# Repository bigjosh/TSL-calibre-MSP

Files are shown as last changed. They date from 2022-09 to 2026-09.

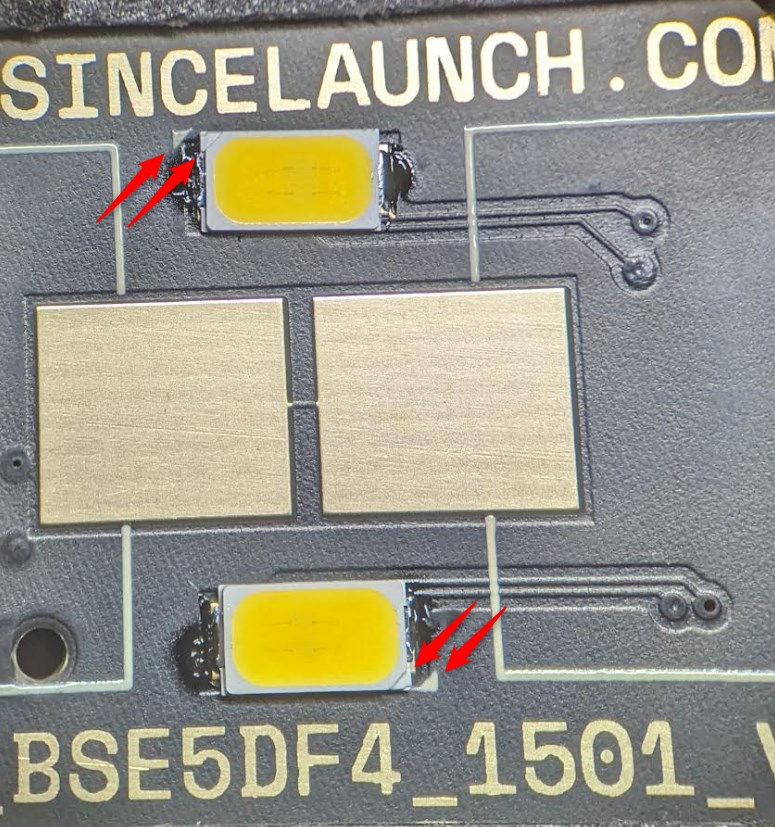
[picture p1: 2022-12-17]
hardware/assembly-package/orientaion-L1-L2.jpg

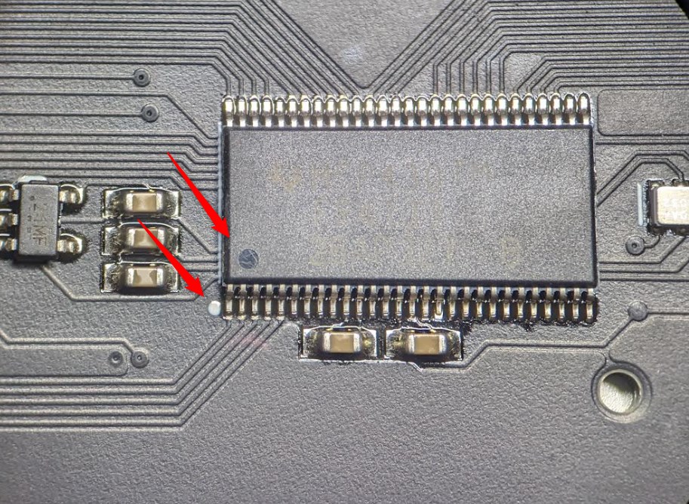
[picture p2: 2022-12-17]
hardware/assembly-package/orientaion-U1.jpg

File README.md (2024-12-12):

# TSL

PCB and firmware for the CW&T Time Since Launch project.



Buy it here...
https://cwandt.com/products/time-since-launch?variant=19682206089275

## Design goals:

* Run for decades on 2xAA batteries.
* Stay accurate to to within ±2ppm over the lifetime.  
* Replaceable batteries, with continued timekeeping during a reasonable battery swap time period.  

## Critical parts:

* MSP430FR4133 processor for LCD driving and supervision
* RV3032-C7 RTC for precision timekeeping
* Custom 12-digit, dynamic LCD glass 
* 2x Energizer Ultimate Lithium AA batteries
* Optional TPS7A0230 3V regulator for generating LCD bias voltage

## Method of Operation

### Ready To Launch mode 

Shows a mesmerizing winding pattern with 1Hz update rate. 

The purpose of this pattern is to show the user that we are ready and willing, and also make apparent any bad LCD segments stuck either on or off. 

We enter this mode on power up if the trigger pin has never been pulled before, and we exit it when the pin is pulled. 

### Time Since Launch Mode

Here we count up the days, hours, minutes, and seconds since the trigger was pulled. 

When we reach 1,000,000 days we switch to Long Now mode. 

### Long Now mode

Shows `999999 999999` blinking forevermore. 

Indicates that the trigger pull was more than 1 million days (~2740 years) ago so we can not display it accurately. 

The idea here is to avoid problems of people trying to ebay old TSL units that have rolled over by misrepresenting their true milage.

#### Errors

##### Error messages 

###### `Pin is in`
ON the first power up after programming, we check to make sure that the switch is closed which indicates that the trigger pin is out.   

##### Error Codes 

Descibed here...
[CCS%20Project/error_codes.h](CCS%20Project/error_codes.h)

### Commisioning

To commisison a new unit, we go though these steps...

1. Firmware is programmed and the display shows `FIRST START` message.
2. Power is removed from the unit.
3. When the unit sees voltage is dropping, it starts counting how many 1/64ths of a second it can keep running before it shuts down. It displays all 8's on the LCD durring this time to check for shorts on the LCD lines.
4. Batteries are insterted and the unit powers up.
5. Firmware checks to see how many 1/64ths of a second it survived during the previous power down. If this value is out of bounds (power level too low or too high) then it shows an `AMPS LO` or `AMPS HI` error.
6. The pin is inserted, depressing the trigger lever. This tests that the pin can cycle though both states.
7. Unit is ready to launch! I displays a segment pattern on the LCD that shoud update at 2Hz. This tests both that the RTC is generating interrupts correectly and also that all LCD are good. 

## Interesting twists

We are using the MSP430's Very Low Power Oscilator (VLO) to drive the LCD since it is actually lower power than the 32Khz XTAL. It is also slower, so more power savings. 

We do NOT use the MSP430's "LPMx.5" extra low power modes since they end up using more power than the "LPM4" mode that we are using. This is becuase it takes 250us to wake from the "x.5" modes and durring this time, the MCU pulls about 200uA. Since we wake 2 times per second, this is just not worth it. If we only woke every, say, 15 seconds then we could likely save ~0.3uA by using the "x.5" modes. 

To make LCD updates as power efficient as possible, we precomute the LCDMEM values for every second and minute update and store them in tables. Because we were careful to put all the segments making up both seconds digits into a single word of memory (minutes also), we can do a full update with a single 16 bit write. We further optimize but keeping the pointer to the next table lookup in a register and using the MSP430's post-decrement addressing mode to also increment the pointer for free (zero cycles). This lets us execute a full update on non-rollover seconds in only 4 instructions (not counting ISR overhead). This code is here...
[CCS%20Project/tsl_asm.asm#L91](CCS%20Project/tsl_asm.asm#L91)

## Battery changes

Based on power projections, we do not expect to need a battery change for at least 100 years. When the batteries get near thier end of life, the LCD will start to get dim. At this point, as long as the unit has been triggered, it will simply stop counting durring the time it takes to change the batteries, and will start counting again
from where it left off once the new batteries are installed. To make this possible, we keep counters of both days and minutes elapsed since trigger in FRAM. These counters are updated each minute and day respectively. Do note that this means that every time you remove the batteries, the time since launch will round down to the most recent minute. Also note that it is _possible_ to lose power exactly at the momentthat happens once per day when both the minute and day counters are updates, so there is lock code to make sure this pair of updates is atomic. 

Note that if the batteries are pulled before the unit is triggered then it will go into `BATT_ERROR_PRELAUNCH` mode ("ERROR 1"), so do not wait *too* long before triggering your TSL. :)

## Hardware revisions

The 2nd hardware revision was produced mid-2024 and removes the backup capacitors connected to the RTC and adds a new 10K OHM resistor on one of the pads that these capcitors used. Previously, these capacitors would keep the RTC continuously operating durring batter changes, but there some defects on those capacitors and we decided it would be easier to just have the count pause durring battery changes. To support this change, there is a change to the firmware that is not compatible with the old versions of the hardware. This change disables the "backup power" option on the RTC. To compile the firmware to work with this new version of the hardware, you must include `#define C2_IS_10K` in the top of `tsl-calibre-msp.cpp`. 

## Current Usage

| Mode | Vcc=3.55V| Vcc=2.6V |
| - | -: | -: |
| Ready to Launch Running | 1.3uA | 1.2uA | 
| Ready to Launch Static | 1.1uA | 1.0uA | 
| Time Since Launch | 1.8uA | 1.7uA |

3.55V is approximately the voltage of a pair of fresh Energizer Ultra batteries.
2.6V is approximately the voltage when the screen starts to become hard to read. 

Note that voltage drop over time is not expected to be linear with Energizer Ultra cells. These batteries are predicted to spend most of their lives towards the higher end of the voltage range and only start dropping when they get near to their end of life.  

There are gains possible from having fewer LCD segments lit. Not sure how actionable this is. We could, say, save 0.5uA by blinking the Time Since Launch mode screen off every other second. It is likely that Ready To Launch mode's low power relative to Time Since Launch mode is due to the fact that it has only 1 segment lit per digit. 

### Measurement conditions

Production board from initial batch. Bare PCB on my desk (not in tube).  
68F
80%RH

(Higher humidity and temperature tends to increase current consumption. Need some different weather conditions to quantify this!)

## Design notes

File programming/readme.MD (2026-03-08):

# PROGRAMMING

## One-time Set up

### Software
 1. Download `program.py`, 'addrow.py', `getch.py`, and `tsl-calibre-msp.txt` from a release in this repo.
 2. Install Python. (The TSL programming script is in Python)
 connections. 
 4. Install [MSPFlasher](https://www.ti.com/tool/MSP430-FLASHER). (This actually talks to the EZ-FET programming hardware)
 5. Make sure that the MSPFlasher executable is in the search path.

### Hardware

You will need a TI board with an EZFet programmer on it. There are lots and any will do. I used the MSP-EXP430FR4133.

2. Remove all of the jumpers on the programmer board and connect it to the computer via USB.
3. Connect the pins from the EZFet side of the programmer (the side closer to the USB) to the programming connector like this...
    | Programmer pin | TSL pin |
    | - | - | 
    | G | G |
    | 3V3 | V |
    | SBWTDIO | R | 
    | SBWTICK | T |
 
#### Config

If you are not going to use the optional logging spreadsheet, you can leave the `tsl_logscript` environment variable unset or set it to `none`.

If you are going to use logging, see the section below.

## Commissioning Procedure
1. Run the `program.py` program.
1. Connect a new TSL board without batteries to the programming connector.
2. Enter the unit's serial number. 
2. _Confirm_ that the firmware download completes without error.
3. _Confirm_ that the TSL starts, the two LEDs flash, the display shows the 'First Start' message.
4. Disconnect the programming connector. The display should show all 8's and fade out while the unit tests its power consumption. Be sure to hold the board by the edges - just touching the LCD pins can increase the power usage enough to cause the power test to fail. 
5. Within 1 minute, install the batteries into the TSL.
6. _Confirm_ that the display shows the 'Load Pin' message.
7. Assemble the TSL into the tube.
8. Insert the pull pin.
9. The display should show 'Arming' followed by the `Ready To Launch Mode` dancing dashes animation.
9. _Confirm_ that the dancing dashes display lights all the LCD segments and that it updates steadily once per second. 
10. Pack it up and ship it out!

Reject the unit if it fails any of the _confirm_ steps above.

## Optional features

### Logging spreadsheet

We optionally keep a record of every TSL programming event in a google sheet using a google app script. 

If you do not want to use this feature, leave `tsl_logscript` unset or set it to `none`.

If you do want to use logging...

6. Create a google spreadhseet with 5 columns and give them names like "Timestamp",	"Device Serial Number",	"Device UUID",	"Firmware Hash", "Programmer Mac Address" and freeze the top row.
 7. Add a webapp to the sheet with "Extentions->Appscript" and paste the code from `addrow-appscript.gs` (in this folder) into the code editor.
 8. Click "Deploy->New Deploy" and select "Run as" you and "Allow anyone".
 9. Click "Deploy" and copy the URL it gives you. 
 9. Set the envrironment variable `tsl_logscript` to this URL.

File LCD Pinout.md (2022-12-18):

## Software considerations

We want to make make sure that all segments for a given digit are accessible with a single write so that we can quickly update that digit and also not mess up any other digits. This is especially true for the most frequently updated digits like the seconds but not as important as, say, day digits since these are updated so infrequently. 

Each digit has 7 segments, and on the LCD they are arranged so that those segments are addressed via 2 segment pins * 4 common pins. 

We are using a 4-mux LCD and in this mode the MSP430 puts 2 physical pins in each writeable LCD memory register. In each MSP430 LCD memory byte, the lower 4 bits are the the 4 common pins for one segment pin and the upper 4 bit are the 4 common pins on the next segment pin. Each segment pin has a logical name starting with "L0" and counting up to "L37".

Importantly note that the pairs are always an even then odd pin number since they start at `L0/L1`. So `L22` and `L23` can be connected to the same digit on the LCD since we can update both with a single write to `LCDM11`, but if we connected LCD digit #1 to MSP pins `L21` and `L22` then we would need to write to both `LCDM11` and `LCDM10` to update the digit on the LCD display (and mess up whatever was on `L23` and `L20`).

Note that the MSP430 is a 16 bit processor, so it is also possible to update two digits with a single word write if the registers connected to them are next to each other in memory and do not cross a word boundary. This is probably only worth the additional effort to save a single cycle in the seconds digits. 

## PCB Layout considerations

Additionally we want to be able to optimize the layout of the traces to keep them short and non-overlapping. Luckily the MSP-430FR411 gives us flexibility to map the LCD common pins to any of the `L` pins on the MSP, so we can map them to `L08`-`L11` which are in the upper left corner of the MSP430, physically corresponding to the location of the common pins on the LCD.

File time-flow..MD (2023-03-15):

### Time Flow in the TSL

Naively, we should just be able to program the RTC to give us one tick per second and then just count those seconds and be done. Unfortunately, we need to be able to change the batteries, and while the batteries are out the MPU is not running so it misses counts. This leads to much complication. Here is how we solve it.

## Pre-launch

We want to be able to tell when a unit launched so we can restart it just in case there is some failure.

To do this, when we commission the TSL in the factory, we write a block to FRAM with the timedate that the RTC was first powered up. Now by adding the accumulated time to the stored time, can can determine the real world timedate. Note that we also store this commission timedate in a database , so the one in FRAM is just a backup in case that database is lost over the eons. Also note that this recorded commissioning time is never used in the operation of the unit - it is only there for forensic inspection in the case of a failure.  

There is a complication- the RTC does not store centuries so if a user waits 101 years before pulling the trigger then we can not tell if this was 1 year or 101 years by looking only at the data. We resolve this for TSLs that have had the triggered pulled (the only case where this matters) by looking to the time since launch to disambiguate how many centuries have past since manufacturing and then allocate them between pre- and post- launch periods. 

# Ready to Launch mode

When the trigger is pulled, we read the current timedate from the RTC (which represents the time since commissioning modulo 100 years) and write it to an FRAM block as the "launch" time. Note that this is only here for forensic purposes and is never used by the unit. We then reset the RTC to 1/1/00 00:00:00 and let it start counting. This way the time in the RTC represents the amount of time since launch. After that, the unit starts counting the ticks and updating the display. Note that we do not ever use the timeday being maintained inside the RTC during operation - the MCU keeps its own timedate based on counting ticks.

The MCU keeps the seconds, minutes, and hours in registers for efficiency. It keeps the day count as an unsigned long in FRAM.  

# Battery change event

During a battery change, the MCU is powered down but the RTC continues timekeeping using a backup capacitor that can keep it running for at least a minute.

So when we power back up again after a battery change, the seconds, minutes, and hours registers are lost - but we can read these from the RTC. 

We do still know the day count because that was stored in FRAM, but there is a complication. What if the battery is pulled at 23:59:59 and then reinserted at 00:00:30? Now we will have the correct seconds, minutes, and hours but will will have missed a day. 

To resolve this, we keep an extra flag in FRAM called `bottom_of_day_flag`. We set this flag when hours goes from 11 to 12 and clear it when we count a new day (hours goes from 23 to 0).

In Ready To Launch mode

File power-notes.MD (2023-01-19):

# Power Notes

All measurements taken with display initialized to "bA9876543210".

Vcc= 3.51V.

2.12uA Count switching between 00 and 01 at 2hz. 
2.00uA with ~INT unplugged so no interrupts or display updates, display at 01.

0.39uA just RTC with 2.hz ~INT and direct switching mode.

2.05uA with RTC connected
1.67uA without RTC connected

### RTC Backup Modes Power Usage
1.23uA RTC at default power up with clkout 32768
0.17uA RTC with clkout disabled, backup disabled
0.18uA RTC with direct switchover mode enabled

-- So direct switchover mode is very power cheap, so probably not worth adding a diode to save 0.01uA.

#### RTC Periodic Timer Power Usage

0.40uA RTC with 2Hz periodic timer off the 4096Hz base
0.34uA RTC with 1/64Hz periodic timer off the 64Hz base.
0.34uA RTC with 1/4096Hz periodic time off the 1Hz base.

--So the periodic timer uses ~0.16uA even on low base frequencies. Wish I had know that before!

0.18uA RTC with 1Hz square wave on clkout

--So clkout is the efficient way to go. :/

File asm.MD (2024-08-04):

# Why Assembly?

We use pure assembly in the `tsl_asm.asm` file for running in Time-Since-Launch mode because it saves power.

The fastest I could do using pure C was to use a RAM table of words that gets written to the LCD memory on each tick. The code looks like this...

```
__interrupt void rtc_isr(void) {
	if (mode=TSL_MODE) {
		*secs_lcdmem_word = secs_lcd_words[  secs ];
		secs+;
		if (secs==60) {
			/* Handle next minute */
		}
	}
 	CBI( RV3032_CLKOUT_PIFG , RV3032_CLKOUT_B );      // Clear the pending RV3032 INT interrupt flag that got us into this ISR.
}
```

The compiler didn't handle the memory to memory assignment so Well, so I optimized it to...

```
__interrupt void rtc_isr(void) {
	if (mode=TSL_MODE) {
        asm("        MOV.B     &secs+0,r15           ; [] |../tsl-calibre-msp.cpp:1390| ");
        asm("        RLAM.W    #1,r15                ; [] |../tsl-calibre-msp.cpp:1390| ");
        asm("        MOV.W     secs_lcd_words+0(r15),(LCDM0W_L+16) ; [] |../tsl-calibre-msp.cpp:1390|");
		secs+;
		if (secs==60) {
			/* Handle next minute */
		}
	}
 	CBI( RV3032_CLKOUT_PIFG , RV3032_CLKOUT_B );      // Clear the pending RV3032 INT interrupt flag that got us into this ISR.
}
```

....which executes in 43.6us per tick. 

This is very inefficient because the compiler generated ISR saves and reloads the registers on each call, even though *we* know that nothing else can run since the CPU is sleeping between ticks. 

So it seems the only solution is to write directly in asm where we can load the registers up once on starting the mode and then even load them again. 

Here is the oltimate ASM code to update the seconds digit on each tick...

```
TSL_MODE_ISR

 	  		;OR.B      	#128,&PAOUT_L+0  			; Set DEBUGA for profiling purposes.

 	  		; These next 3 lines are where this product spends the *VAST* majority of its life, so we hyper-optimize.

 	  		MOV.W		@R6+,&(LCDM0W_L+16)			; Read word value from table, increment the pointer, then write the word to the LCDMEM for the Seconds digits

			CMP.W		R6,R5						; Check if we have reached the end of the seconds table (seconds incremented to 60)
			JNE			TSL_DONE					; This takes 2 cycles, branch taken or not

			; Next minute
```

We utilize the MSP430's auto address increment mode to load, store, and increment all in a single instruction.

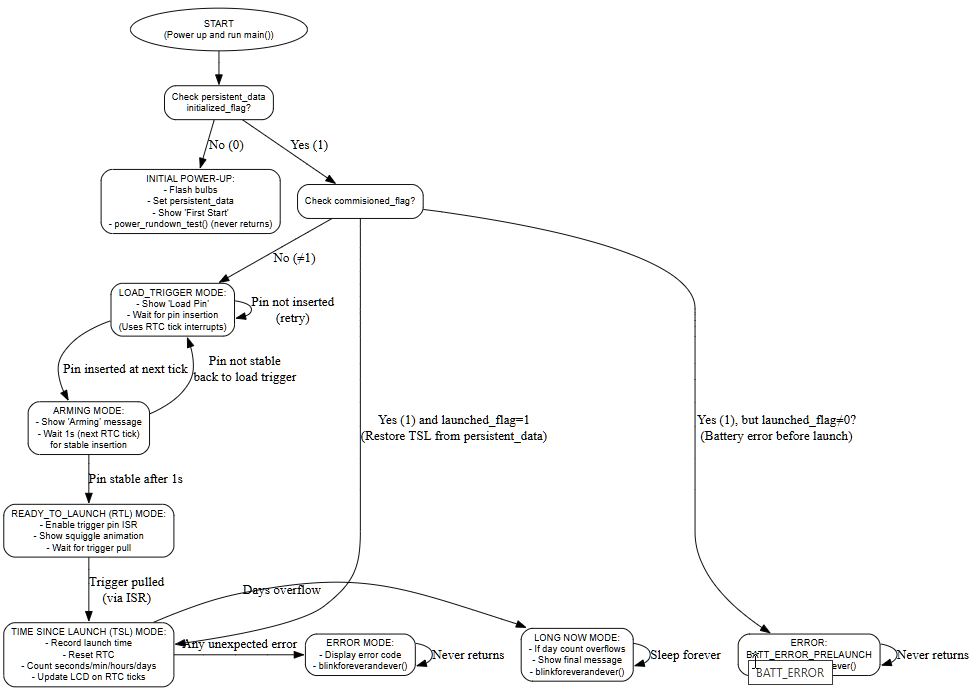
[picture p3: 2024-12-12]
flowchart.png

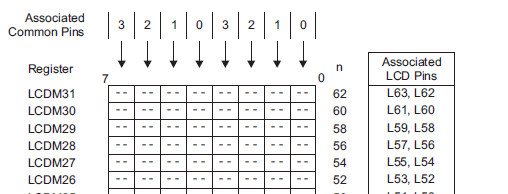
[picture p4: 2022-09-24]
MSP430 LCD memory map.png

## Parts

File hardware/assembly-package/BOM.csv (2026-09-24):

RefDes | Name | Value | Manufacturer | Place | Subsitution | Budget Price at 1K units | URL
C1 | CAP_0603 | CAP CER 1UF 16V X7R 0603 | Murata |  | Possible | 0.02 | https://www.digikey.com/en/products/detail/taiyo-yuden/EMK107C6105KA-T/6563455
C3 | CAP_0603 | CAP CER 1UF 16V X7R 0603 | Murata |  | Possible | 0.02 | https://www.digikey.com/en/products/detail/taiyo-yuden/EMK107C6105KA-T/6563455
C4 | CAP_0603 | CAP CER 1UF 16V X7R 0603 | Murata |  | Possible | 0.02 | https://www.digikey.com/en/products/detail/taiyo-yuden/EMK107C6105KA-T/6563455
C5 | CAP_0603 | CAP CER 1UF 16V X7R 0603 | Murata |  | Possible | 0.02 | https://www.digikey.com/en/products/detail/taiyo-yuden/EMK107C6105KA-T/6563455
C7 | CAP_0603 | CAP CER 1UF 16V X7R 0603 | Murata |  | Possible | 0.02 | https://www.digikey.com/en/products/detail/taiyo-yuden/EMK107C6105KA-T/6563455
C8 | CAP_0603 | CAP CER 1UF 16V X7R 0603 | Murata |  | Possible | 0.02 | https://www.digikey.com/en/products/detail/taiyo-yuden/EMK107C6105KA-T/6563455
R1 | RES_0605 | RES 10K OHM 0805 | Stackpole |  | Possible | 0.01 | https://www.digikey.com/en/products/detail/stackpole-electronics-inc/RMCF0603FT10K0/1761235
J1 | LCD | 30PIN TN Positive 12 Digit 7 Segment | Supplied by customer | DNP |  | 1 | na
J3 | Programming pads | PDI-6 |  | DNP
L1 | Flash LED | 62-227ET/KK7D | Everlight High Power LEDs |  | Possible | 0.16 | https://www.digikey.com/en/products/detail/everlight-electronics-co-ltd/62-227ET-KK7D-3M5050X6Y62629U6-2T-EU/7930856
L2 | Flash LED | 62-227ET/KK7D | Everlight High Power LEDs |  | Possible | 0.16 | https://www.digikey.com/en/products/detail/everlight-electronics-co-ltd/62-227ET-KK7D-3M5050X6Y62629U6-2T-EU/7930856
Q1 | MOSFET Transistor | 2N7002K | NXP-Philips |  | Possible | 0.05 | https://www.digikey.com/en/products/detail/rohm-semiconductor/RK7002BMT116/4924083
Q2 | MOSFET Transistor | 2N7002K | NXP-Philips |  | Possible | 0.05 | https://www.digikey.com/en/products/detail/rohm-semiconductor/RK7002BMT116/4924083
S1 | Switch | Custom two part latch switch | Supplied by customer |  |  | 0.63 | na
U1 | MCU | MSP430FR4133IG56 | TI |  |  | 1.15 | https://www.digikey.com/en/products/detail/texas-instruments/MSP430FR4133IG56/5067017
U2 | RTC | RV-3032-C7 | Micro Crystal |  |  | 2.95 | https://www.digikey.com/en/products/detail/micro-crystal-ag/rv-3032-c7-32-768khz-2-5ppm-ta-qa/16273065
U3 | REGULATOR | TPS7A0230PDBVR | TI |  | Possible | 0.5 | https://www.digikey.com/en/products/detail/texas-instruments/TPS7A0230PDBVR/12165118
U4 | Battery Holder | KEYSTONE1024 | Keystone |  |  | 1.601 | https://www.digikey.com/product-detail/en/keystone-electronics/1024/36-1024-ND/2178268
U5 | Battery Holder | KEYSTONE1024 | KeyStone |  |  | 1.601 | https://www.digikey.com/product-detail/en/keystone-electronics/1024/36-1024-ND/2178268
T1 | Test pads | CAP_0603 |  | DNP

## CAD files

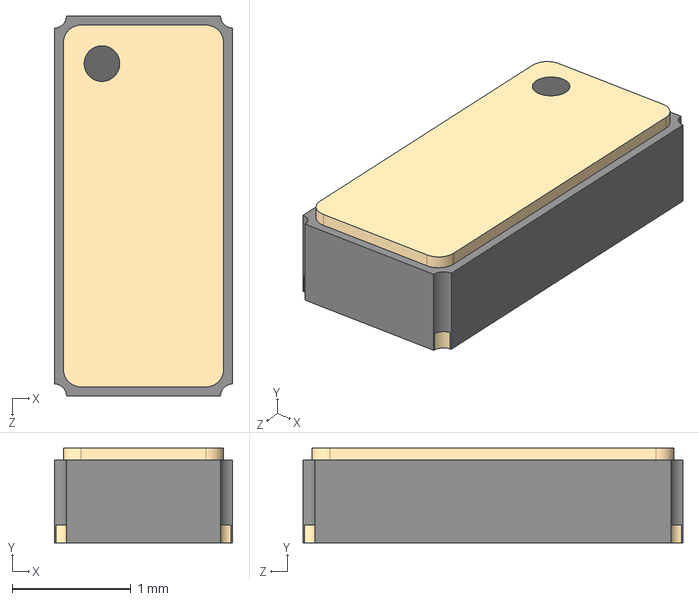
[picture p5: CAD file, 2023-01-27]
hardware/diptrace/3d/RV-3032-C7-32.768KHZ-3PPM-TA-QA.STEP
1.50 x 0.8 x 3.20 mm

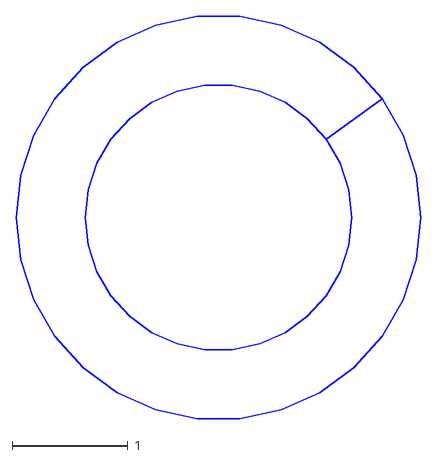
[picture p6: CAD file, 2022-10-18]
hardware/diptrace/mounting hole anulus shape phase2.dxf
3.50 x 3.48

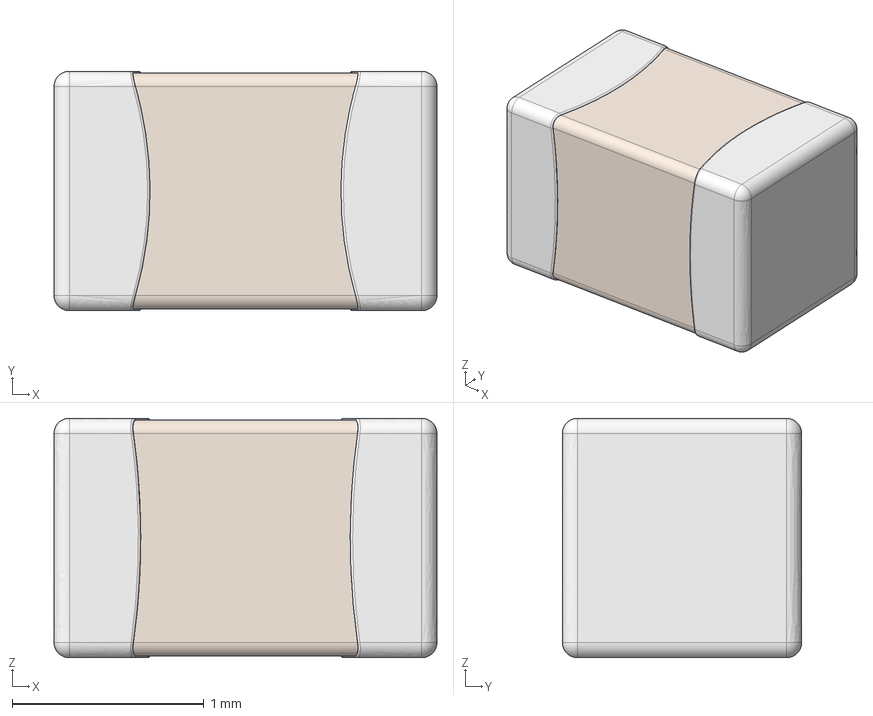
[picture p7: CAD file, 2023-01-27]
hardware/diptrace/3d/Ceramic_Capacitor_0805_h50mil.step
2.00 x 1.25 x 1.25 mm
Pin1
Pin2
CeramicBody

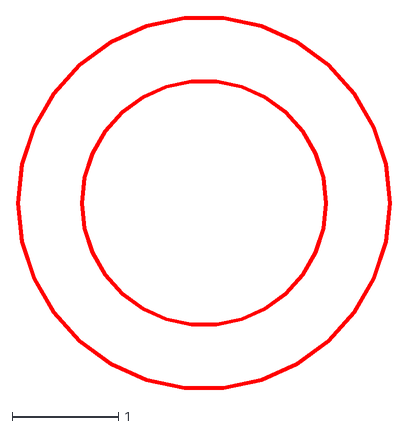
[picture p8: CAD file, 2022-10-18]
hardware/diptrace/mounting hole anulus shape phase1.dxf
3.53 x 3.51

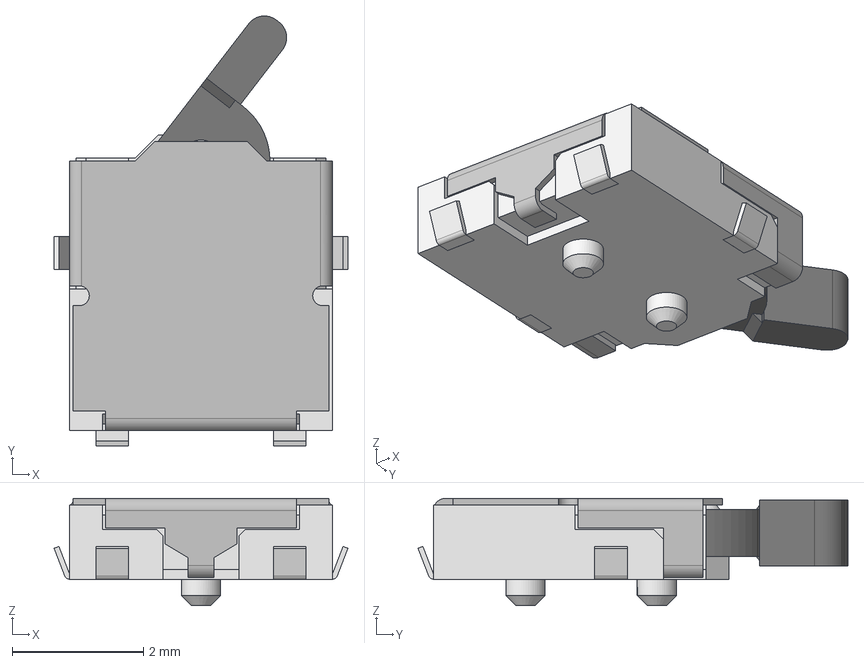
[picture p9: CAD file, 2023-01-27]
hardware/diptrace/3d/ESE18R61B.step
4.47 x 6.54 x 1.63 mm

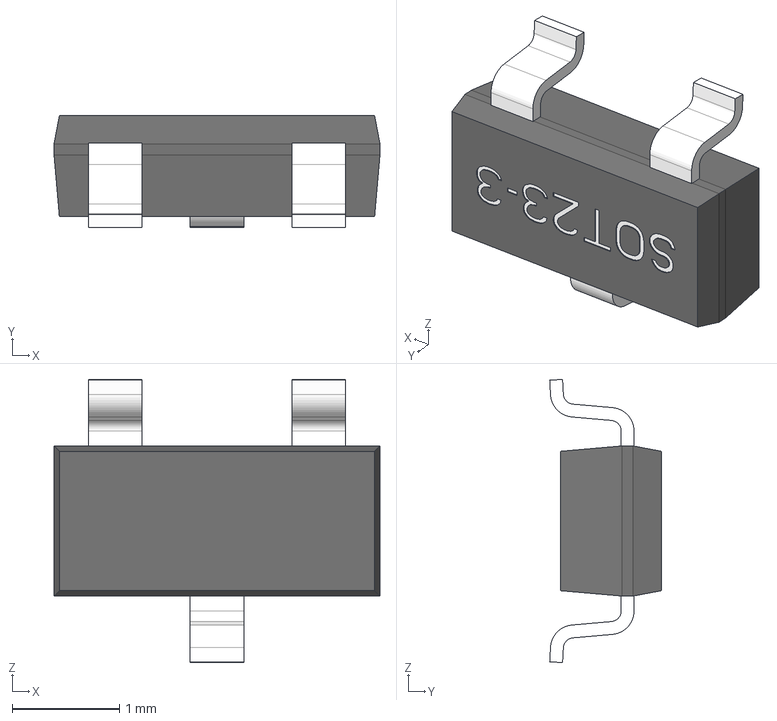
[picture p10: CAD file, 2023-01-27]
hardware/diptrace/3d/sot23-3_p0-95_l3-04_w1-4.stp
3.04 x 1.04 x 2.64 mm

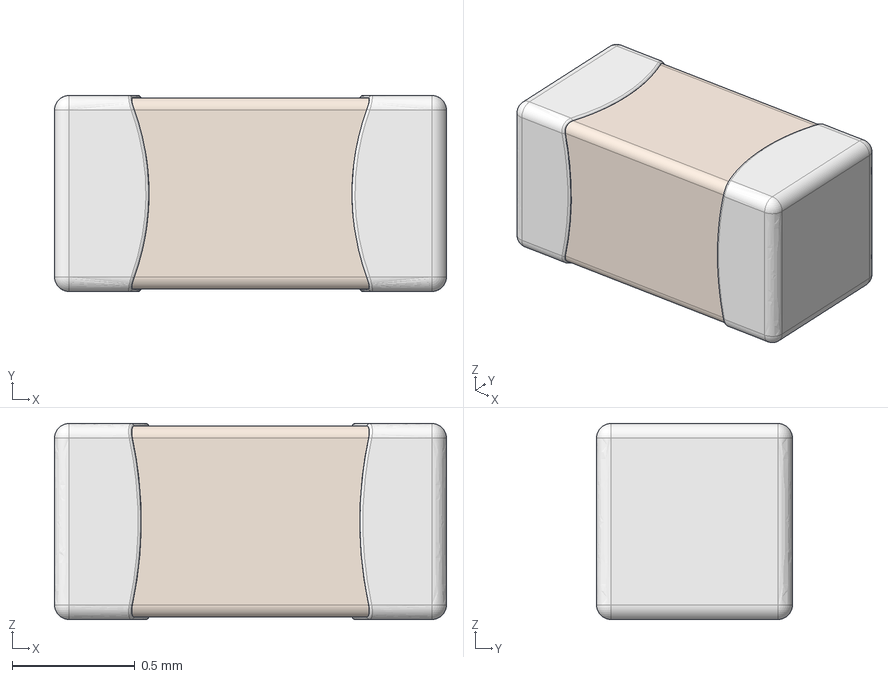
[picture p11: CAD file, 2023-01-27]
hardware/diptrace/3d/Ceramic_Capacitor_0603_h32mil (1).step
1.60 x 0.8 x 0.8 mm
Pin1
Pin2
CeramicBody

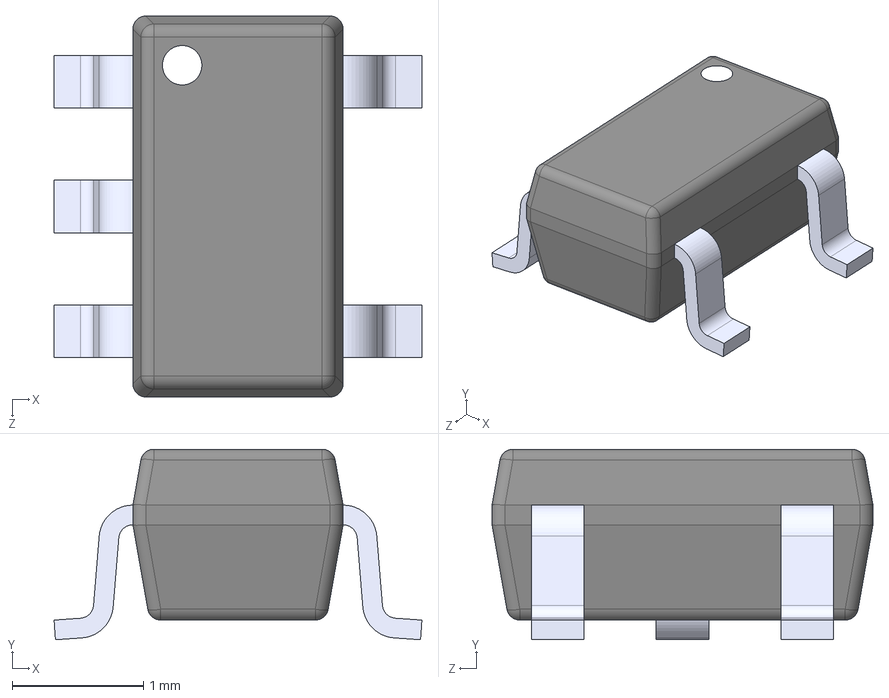
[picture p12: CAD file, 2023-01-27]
hardware/diptrace/3d/SOT95P280X145-5N.step
2.80 x 1.45 x 2.90 mm

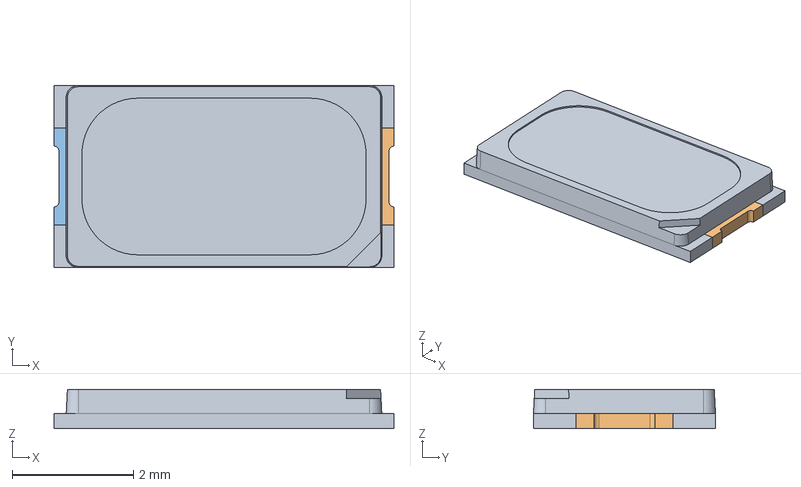
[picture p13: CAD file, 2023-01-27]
hardware/diptrace/3d/62-217D.STEP
5.60 x 3.00 x 0.65 mm
62-127D-1

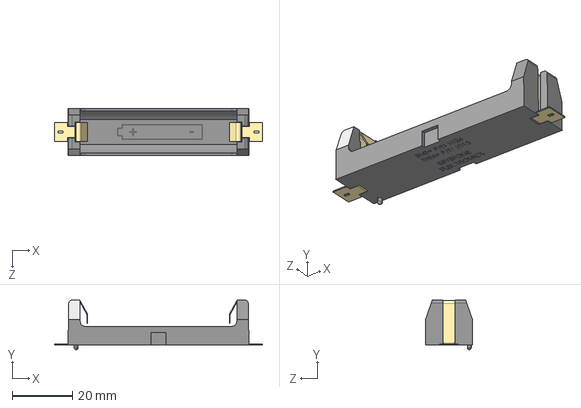
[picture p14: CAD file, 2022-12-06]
hardware/diptrace/3d/keystone-PN1024.STEP
68.9 x 16.4 x 15.5 mm

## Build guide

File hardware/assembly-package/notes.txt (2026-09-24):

1.
No ultrasound cleaning - RTC clock part U2 is sensitive to vibration.

2.
LCD parts are to be hand soldered. The LCD face on the TOP side of the PCB. LCD 
must have clearance above parts below. Use a jig or shim to maintain uniform 1.6mm 
clearance between LCD bottom and PCB top while solderning. Soldering to be done from
the BOTTOM side of PCB. 

3.
LCD part is heat sensitive. Avoid overheating when soldering. Solder alternating
pins to avoid over heating LCD. 

4.
Use the solder reflow profile for RTC clock part U2, included in this directory. 

5.
Parts U1, U2, L1, & L2 are orienation sensitive. See photos in this directory for proper
rotation.

6. See mousebites.png for suggested location mouse bites if required.

8.
PCB Parameters
Layer:2 Layers
Material:FR-4
Thickness:1.6 mm
Solder Mask:Matt black
Silkscreen:White (Silk layer may be omitted)
Surface Finish:Immersion gold(ENIG) (1U")

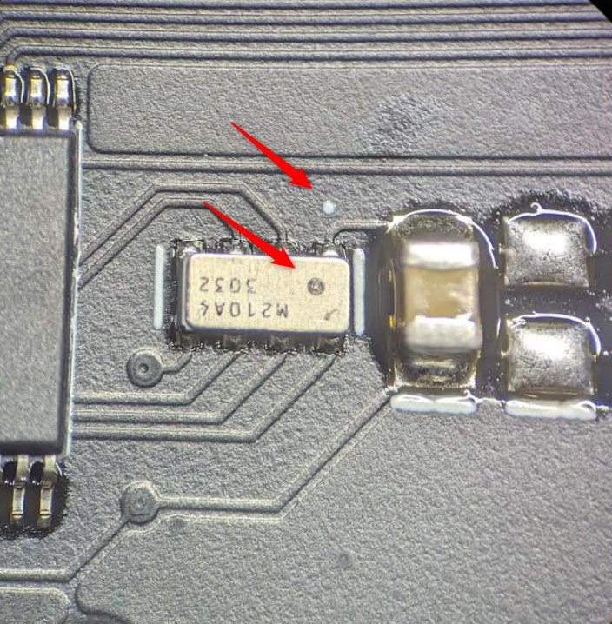
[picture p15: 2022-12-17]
hardware/assembly-package/orientaion-U2.jpg

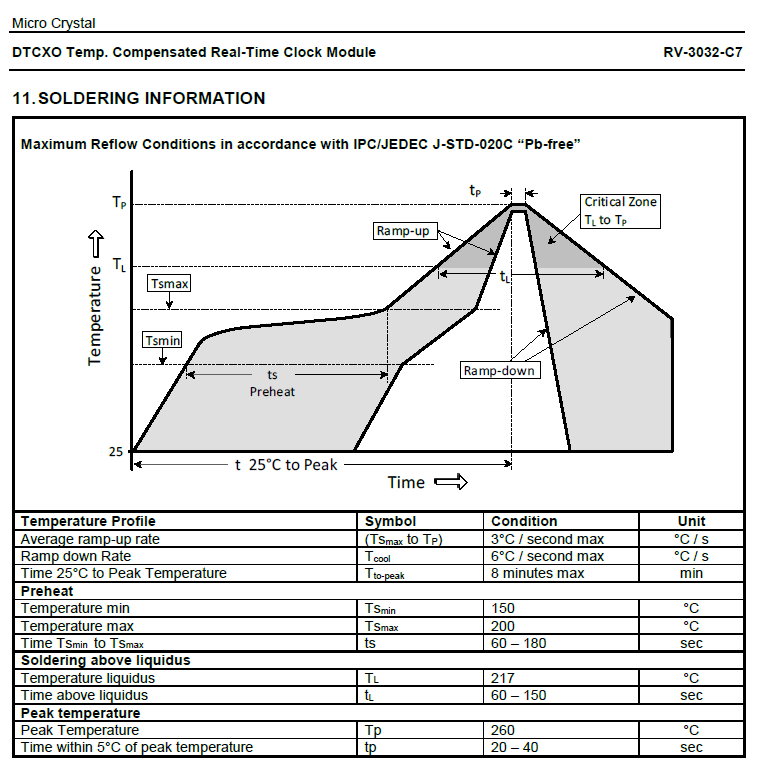
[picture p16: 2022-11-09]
hardware/assembly-package/RV3032-C7 reflow profile.png

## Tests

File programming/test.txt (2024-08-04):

@1800
51 19 01 02 31 07 24 FF FF FF FF FF FF FF 01 00
FF 00 FF FF 2F 00 00 00 FF FF FF FF FF FF FF FF
FF FF FF FF FF FF FF FF FF FF FF FF FF FF FF FF
FF FF FF FF FF FF FF FF FF FF FF FF FF FF FF FF
FF
q

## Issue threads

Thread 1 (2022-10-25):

LCD pins do not fit in holes

bigjosh, 2022-10-25:
Double checked and we match the factory supplied drawing, so maybe this is just because we have protype LCDs that were hand assembled?

Test again with production LCDs and adjust if necessary.

Our pattern:
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

Factory drawing:
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

Closed 2022-10-28.

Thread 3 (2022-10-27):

Move ~INT and toggle switch to different PORT pins?

bigjosh, 2022-10-27:
So they can have independent ISRs for slight power saving in Ready To Launch mode.

bigjosh, 2022-10-27:
It would need to be on P2 since that is the only other port that has pin change ints on this chip.

Maybe move one of the less-used LCD pins to a P6 l-pin to free up a P2 pin for the trigger?

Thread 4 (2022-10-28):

Maybe move trigger pin up a little?

bigjosh, 2022-10-28:
Current location just seems wrong and prone to having the pin break off. Maybe a little higher would be better?

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

cheewee2000, 2024-07-08:
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
i think the offcenter ness is OK. the part is positioned to make the lever centered to the pin.

bigjosh, 2024-07-09:
Hmmm. Ideas:

1. Extend the taper of the pin so that it goes up to the middle of the switch arm bearing surface. Seems like this would reduce the sliding up/down force on the switch arm so it would not break? Nice because no PCB changes.
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

3. Make the pin (or at least a section of the pin near the PCB) out of high permeability metal. Put a magnet on one side of the pin and a reed switch on the other. When pin is in place, the field mostly is diverted though the pin. When the pin is removed, the field goes across the hole and closes the reed switch. Nice because no physical contact between pin and PCB. Maybe slight chance that unit could be triggered by big external magnetic field, but I think we can make that very unlikely if we lay everything out well.

The switch-failure-on-pull is so demoralizing, we have to fix it!

bigjosh, 2024-08-27:
Considering new defects with the trigger pin switch, best to get rid of it altogether.

How about replacing it with a piece of spring that goes across the PCB gap like this...

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

To load the TSL, you have to insert the pin unto the end cap and then insert the PCB into the end cap slot. The pin pushes the spring off of the contact point as you slide it in. When the user pulls the pin, the spring returns back to the contact, closing the circuit and starting the count. Nice side effect is that after the pin is pulled once, the spring is completely out of the way and never touches the pin again when the pin is taken out and reinserted later. The user never even sees the spring unless they disassemble the unit and unscrew the PCB from the endcap.

The end of the spring and the contact could be gold plated where they touch for extra protection. But remember that this switch only has to close once!

cheewee2000, 2024-08-27:
i love this solution!  So if we go with this trigger, we would load the firmware with the pin already loaded? or do we assemble the cap with the pin inserted after loading the firmware?

bigjosh, 2024-08-27:
We would want to test that both opened and closed states work, and probably the easiest way to do this is from the firmware.

So maybe...

1. program the firmware into the PCB (tests switch closed)
2. load batteries & mount PCB into endcap with pin inserted in the endcap (tests switch open)
3. assemble pcb+endcap into tube

Note that these steps can have long delays between them.

See any problems with this workflow?

cheewee2000, 2024-08-28:
this should work!

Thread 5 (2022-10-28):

Eliminate flash LEDs?

bigjosh, 2022-10-28:
Seems inelegant compared to the rest of the design.

Four extra parts for 200ms that I think most people don't even see?

And at current power levels, that little flash uses up several years of runtime!

If you are going to flash, invest in the R&D to make a real metal oxidation-based flash bulb that will be special and people will actually see!

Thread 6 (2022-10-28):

No reverse battery protection

bigjosh, 2022-10-28:
Could be added for the cost of a diode, but no one will ever be changing the batteries on these. Maybe better to just put a little note under a battery saying (1) change them quick, and (2) don't put them in backwards - just in case. Also anecdotally the design seems to be able to survive brief reverse polarity.

bigjosh, 2022-10-31:
Anecdotally I have accidentally connected the power supply backwards a couple of times and everything seems to be ok, so probably do not need any protection (especially since no one will every change these batteries ever anyway). Should test more.

Closed 2022-12-15.

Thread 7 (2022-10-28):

How to drive LCD voltage?

bigjosh, 2022-10-28:
1. Direct from Vcc. Pro=No parts, simple. Con=Contrast a little harsh when batteries are fresh, and changes as they go down. Slightly higher power consumption.
2. Internal regulator. Pro=No parts, prefect contrast control. Con=Significantly higher power usage.
3. External regulator. Pro=Prefect contrast control, lowest power consumption. Con=Extra parts.

bigjosh, 2022-10-31:
# Some data
All collected in one sitting with at Vcc=3.46V, No RTC connected,  Joulescope on 180uA scale

| V33 Voltage | Source | Draw | Notes |
| -: | - | - | - |
| 3.46V | Vcc direct | 1.98uA | |
| 3.02V | Internal regulator | 3.86uA | Reference in switched mode |
| 3.00V | External TPS7A0230 regulator  | 1.79uA |  |
| 2.96V | Internal regulator | 3.83uA | Reference in switched mode |
| 2.80V | External TPS7A0228 regulator* | 1.69uA |  |
| 2.78V | Internal regulator | 3.62uA | Reference in switched mode |

\* 0.1uF directly on input and output of regulator on breadboard

bigjosh, 2022-11-04:
Taylor picks the 3.0V regulator!

Closed 2022-11-04.

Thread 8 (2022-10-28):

MSP430 does not reset automatically after programming with EZ-FET

bigjosh, 2022-10-28:
Can this really be true? Seems 100% reproduceable.

bigjosh, 2022-10-31:
This seems to have been related to having one of the regulators incorrectly wired into the MCU. Reopen if seen again now that this is fixed.

Closed 2022-10-31.

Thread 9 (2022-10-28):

Pick a height for the LCD above the PCB

bigjosh, 2022-10-28:
Must be high enough to clear all components with variation.

Make a jig or shims to enforce this.

bigjosh, 2022-11-04:
A 1.6mm PCB is a nice height for a shim if you stick under both ends of the LCD. Just clears the components.

bigjosh, 2023-01-31:
I guess 1.6mm it is.

Closed 2023-01-31.

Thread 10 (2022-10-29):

Quickly ramping up voltage seems to trigger a high current mode?

bigjosh, 2022-10-29:
Happened once with the variable power supply, ramping at about 1V/s

bigjosh, 2022-10-29:
This could happen right after a fresh battery changeout

bigjosh, 2022-10-31:
Seems like result of floating input pin on MSP430.

Closed 2022-10-31.

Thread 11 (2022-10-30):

Add external pull-down resistors for SCL and SDA, tie EVT to ground

bigjosh, 2022-10-30:
These will make sure those pins do not float in case of battery change event in noisy environment. The RV3032 sucks so much juice if input pins float, and these are all the input pins.

We never use `EVT` to just tie it low.

Ror `SCL` and `SDA` we only need them at power up and when pin is pulled, so only a insignificant extra power draw. Resistors must be big enough that the internal `SDA` pull-up can win (does not matter for `SCL` since we can fully drive it). We can always leave these resistors unpopulated if testing shows they are not needed.

bigjosh, 2022-10-31:
Seems we are using Direct Switching mode as per #12. This mode automatically disables the i2c pins as soon as Vcc starts dropping, so seems these external pulldowns are unnecessary. Need to test.

Closed 2022-10-31.

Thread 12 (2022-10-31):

How to isolate RTC during battery change

bigjosh, 2022-10-31:
We want to RTC to keep running on the backup caps during a battery change. The RV3032 has built-in backup-switchover capabilities, but they use power. The lowest power one is "direct switchover" that switches when Vcc<Vbackup.

bigjosh, 2022-10-31:
# Data

Power used which Vcc=3.46V, Joulescope on 180uA scale, always same digits on LCD (changing one segment will throw off these readings!).

| Mode | Power | BSM | Description |
| - | - | - | - |
| No RTC | 1.90uA | na | Control test |
| Disabled | 2.15uA | 00 | Switchover disabled |
| DSM | 2.14uA | 01 | Direct switching mode |
| LSM | 10.89uA | 10 | Level switching mode |
| Disabled | 2.19uA | 11 | Seems to be the same as 00 disabled |

Hmm... Disabled seems too high compared to DSM. Let's try again at 18uA range in case something is getting lost in the noise?

| Mode | Power | BSM | Description |
| - | - | - | - |
| No RTC | 1.80uA | na | Control test |
| Disabled | 2.15uA | 00 | Switchover disabled |
| DSM | 2.15uA | 01 | Direct switching mode |

bigjosh, 2022-10-31:
Seem direct switching mode does not use measurably more current than disabled mode, so no need to even investigate using an external diode since we get the internal one for free with direct mode.

Closed 2022-10-31.

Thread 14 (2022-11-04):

Add some animation on the half ticks?

bigjosh, 2022-11-04:
Because of limitations of the RV3032 mode we are using, we get a free half tick every 500ms.

Should we use this for anything? Blink something?

Currently we wake and then just go back to sleep without doing anything.

bigjosh, 2022-11-09:
Current firmware shows a little tick/tock animation in the leftmost digit just to visualize that the alternate ticks are happening.

bigjosh, 2023-01-31:
No more half ticks since switch from periodic timer to `clkout`.

Closed 2023-01-31.

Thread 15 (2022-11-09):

Need to specify minimum amount of backup hold-over time for battery change

bigjosh, 2022-11-09:
How long does the RTC need to keep time while the batteries are out during a battery change?

60 seconds? 120 seconds?

Depending on the answer we can likely either depopulate and/or lower the capacitance of some of the (currently 3) backup 47uF capacitors. Which one to do depends on how much PCBA placements cost compared to the price difference of lower value capacitors.

bigjosh, 2022-12-16:
Spec'ed at 90 seconds by Taylor.

bigjosh, 2022-12-16:
Calculation:

We want to see how long it will take for the backup capacitors to drop from 2.3V to 1.3V (1 V).  2.3V is where the LCD starts getting really dim. 1.3V is when the RTC cuts out.

We want to back up for 90 seconds.

The RTC is drawing about 200nA.

Answer: 18uF

1F = 1C / 1V

1C = 1F / 1V

1A = 1C / 1S

1A = (1F / 1V) / 1S

1S = (1F / 1V ) / 1A

90s = ( f / 1V ) / 200nA

90s * 200nA = f / 1V

f = 90s * 200nA / 1V

Answer: 18uF

We need at least 18uF to keep RTC backed up for 90 seconds.

https://frinklang.org/fsp/frink.fsp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

bigjosh, 2022-12-16:
Data:
Tested with 1x47uF backup capacitor and RTC still running after 90 seconds without power, so we can use a single cap here.

Closed 2022-12-16.

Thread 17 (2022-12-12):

LCD goes blank after running ready-to-launch mode animation for a while

bigjosh, 2022-12-12:
Have now seen twice. Happens after several days. Time Since Launch Mode works fine if you pull the pin. Hmmm...

bigjosh, 2022-12-12:
LCD seems to be not actually blank but instead updating very quickly. Maybe the RTC is getting reset to 32khz? But then probably would also loose the programming to output on ~INT?

bigjosh, 2022-12-14:
OK, looking like this is a race condition where the trigger pin glitches so quickly that it sets the IFR but it is gone by the time ISR reads the value on the PORT (probably because of an ESD event).

Should be easy to fix by putting a software glitch filter in the ISR so both the IFR and PORT must be set to trigger, but also that clears the IFR in case it disagrees with the PORT so that the interrupt does not keep firing.

Closed 2022-12-14.

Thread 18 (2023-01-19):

Reduce RTC power usage during the battery change detection period

bigjosh, 2023-01-19:
* Add series resistor to CLKOUT line to reduce power going into MCU clamping diode
* Add pull-down resistors to I2C lines to keep these pins from floating.

These will reduce power usage during the very brief moment during a battery change before the RTC goes into backup mode.

There will likely never be a legitimate battery change, so probably moot.

bigjosh, 2023-01-31:
Not needed. With direct switchover mode the switch happens almost instantly when battery power is removed and `clkout` goes low and i2c pins go hi-Z.

Closed 2023-01-31.

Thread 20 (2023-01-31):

Move ready-to-launch and time-since-launch ISRs and vectors into RAM so we can completely avoid turning on the FRAM controller.

bigjosh, 2023-01-31:
Kinda ugly since TI does not put the RAM vector table in the link script. :/

Luckily we only need two of the vectors (P1 and P2), and they are near the top of the table

bigjosh, 2023-05-05:
Tried this and no noticeable power savings. Not sure why.

We do keep the vector table in RAM just to make it easier to update.

Closed 2023-05-05.

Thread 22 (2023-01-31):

Figure out some way to keep track of centuries.

bigjosh, 2023-01-31:
Unfortunately the RV3032 only has a two digit year register, so we need a way to keep track of when that rolls if we want to support battery changes after 100 years of time-since-launch mode.

Hard part is the edge case where someone pulls the battery just before the 100 year mark and then puts in the new batteries right after.

bigjosh, 2023-01-31:
I think maybe a 50 year interlock that keeps track if it is currently the 1st or 2nd half of the current century, and clicks up a century counter when it sees a transition from 2nd to 1st?

Could be an extra 16 bit countdown counter since 50 years is 18262 days.

bigjosh, 2023-03-15:
OK started implementing this with commit f1c9ab72f2cc5b9a458d60fc3412513ffe53b136.

Harder than first expected becuase we also need to deal with the case where a person pulls the batteries at just the right microsecond (literally) when the century counter record is being updated.  This is EXTREMELY UNLIKELY ([1 in 1.5778463 × 10^15](https://www.google.com/search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)), but hey, we have to do it right!

bigjosh, 2023-05-05:
Close with 90f4e616408fef2881491d895ce1a76b5cfaaab0.

Closed 2023-05-05.

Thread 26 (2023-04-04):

Do we test the flash LEDs as part of commissioning?

bigjosh, 2023-04-04:
We could flash them when the pin is inserted for the first time.

It would use up years of battery life. But maybe we should?

Or maybe flash them right before showing the "first start" message while we are still on power from the programmer? But don't really want the operator to have to look over there to catch it. Hmmm...

bigjosh, 2023-05-05:
As of 2fc57d58cc88050d29e859d61aa53fb882a4cb1e we now flash before the "first start" message.

Closed 2023-05-05.

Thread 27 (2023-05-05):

Make the "Load Pin" mode be low power so it can ship without pin in?

bigjosh, 2023-05-05:
To avoid customs agents pulling the pin. User would then need to "arm" unit before use.

bigjosh, 2023-05-18:
"i think we're OK the way it is. We've been adding a little tear-away sticker over the pin that says "single use". We haven't had any customs agents or kids pulling the pins since." -CW

Closed 2023-05-18.

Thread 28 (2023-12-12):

Switch to 1088 battery holder

bigjosh, 2023-12-12:
Prevents any chance of putting batteries in backwards.

https://www.digikey.com/en/products/detail/keystone-electronics/1088/5118850

Check if there is room for the clip too.

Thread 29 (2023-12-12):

Use FRAM to store time counters, eliminate RTC backup.

bigjosh, 2023-12-12:
So much simpler code. Gets rid of those problematic and expensive backup caps.

Only user impact is that time pauses when there is no battery power, which seems correct.

bigjosh, 2024-07-08:
Seems maybe we can not simply *remove* the backup CAP?...
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

Have a request into microcrystal now to see what that is about.

bigjosh, 2024-07-08:
We can always just sub this for the CAP at 1/2 a cent...
https://www.digikey.com/en/products/detail/stackpole-electronics-inc/RMCF0805JT10K0/1757762

bigjosh, 2024-07-10:
Ok, Microsemi says "You can not leave a CMOS input floating." But I am sceptical. According to the docs, while this is an input in the sense that a current is flowing into a transistor, this is not a gate input. But at least for now, we will put the resistor in since it is low risk. We can always omit it later.

bigjosh, 2024-07-21:
Closed with 03295623e4f3d528dc504cf36cbc0532044c6734

Closed 2024-07-21.

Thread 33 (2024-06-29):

Battery holders can pull pads off in cases of trauma

bigjosh, 2024-06-29:
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

The battery holder was knocked off by trauma, and it took the pad with it. It probably got dropped at some point (perhaps during shipping) and landed with non-pin side first.

To prevent this, we can try making the pads bigger. We can also specify a squirt of glue under each battery holder during assembly, but I don’t like that as much and would probably increase assembly costs.

bigjosh, 2025-09-28:
* make pads bigger and add vias where possible for better anchoring.
* add a squirt of epoxy under each battery holder
* see if thru hole battery holders could work

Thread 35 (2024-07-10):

Turn off VBAT charging in firmware

bigjosh, 2024-07-10:
Since microsemi wants us to add a resistor on VBAT, we need to turn off the charging circuit there or else current will leak though that resistor. This does mean that new firmware will be incompatible with old versions of the PCB that have the cap there.

bigjosh, 2024-07-19:
Closed in commit 9168611150e3ca09b420bda13374fd5a2a95287b

bigjosh, 2024-07-19:
Just remember that old firmware on new PCB will have excessive power consumption, so don't do it!

Closed 2024-07-19.

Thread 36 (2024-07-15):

Test if switching MCLK to VLO saves power in counting mode

bigjosh, 2024-07-15:
Maybe removing all demands for the higher speed clock will leave it off? Running slower uses more power, but maybe leaving off the high speed clock saves even more?

bigjosh, 2024-07-20:
Nope, slightly higher power. And so ssssllloooowwwww.

Closed 2024-07-20.

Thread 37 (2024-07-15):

Add mess eg "Make sure you see a moving squiggle pattern on the screen or else this unit is broken" to pull pin tag

bigjosh, 2024-07-15:
And also to an instruction sheet that you have to look at to take the thing out of the box.

We have to make sure that people recognize that the unit has a problem *before* the big moment.

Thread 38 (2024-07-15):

What should we do if power is lost and restored before pin pull?

bigjosh, 2024-07-15:
Currently we show an error, but with the new `pausable` firmware (#29 ) we could potentially recover seamlessly. The only functional change would be that the RTC would lose its time, so we would no longer know the clock time of when the pull happened which can be handy for debugging problems and replacing units when there is a problem.

I vote that we show a (new) erorr. If we lose power it either means there is a defect with the unit or the user pulled the batteries. If there is a defect, we want to know before they pull the pin so we can swap the unit out.

If the user pulls the battery, well, they shouldn't (#37 ). And we should manifestly be able to tell the difference between a defective unit and a user error (#31 ).

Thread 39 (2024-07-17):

Test for high current draw during commissioning

bigjosh, 2024-07-17:
There are several failure modes that result in the current draw being too high and this will make the batteries go dead prematurely. We should test for this defect before units go to customers.

The easiest way to test this would be to use the built in current measurements on the EZ-FET programming board. Alas, the tools to access this are closed source and the documentation is not usable.

We could make our own current sensor, but then there would need to be a way to integrate that into the programming hardware and too much work.

So here is an idea: during the "First Start" programming step, we wait for the power supply voltage to fall below a given voltage and then we check how long it takes to fall to another lower voltage. During this time between the two voltages, the rate of the decay is dependant on the total power being drawn from the 1uF decoupling capacitor. If we find the current draw was too high, then we can fail the unit on the next step.

I think the best way to implement this is to continuously check the voltage during the "First Start" page. While we are connected to the programmer, the voltage should be 3.3V. Once we disconnect from the programmer it will start falling. When we see it hit, say, 3V then we put up a new message like "A Check" and set an RTC for, say, 1 second and go to sleep. When we wake 1 second later we check the voltage again and if it is above some threshold (2.5V?) then we set a "power draw OK" flag for the next step. If we get to the next step (battery insertion) and that flag is not set, then we know either the voltage was too low, or that the draw was so high that we ran out of juice before we ever woke up.

Closed 2024-07-27.

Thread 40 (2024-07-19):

Should we unlock and then relock the info FRAM every time we update the persistent minutes counter?

bigjosh, 2024-07-19:
It only costs an extra 6 cycles per minute, but does it actually buy us anything? Seems like the only benefit to having that locked is if the MCU flys off and starts writing random data to the FRAM, but can that ever really happen?

```
			; Note that we use MOV to update the SYSCFG0 rather than BIC and BIS because MOV takes 1 fewer cycles.
			; The only downside to this is that we overwrite whatever is in the other bits, but the program memory should
			; always be locked in our application.

			; Note that keeping SYSCFG0 in a register would not speed things up since indirect addressing is always implemented as address+register, they just used R0 if you do not specify one.
			; Is locking/unlock for each update worth it? Well, it only costs about 5 minutes per century: https://www.google.com/search?q=%28100+years%29+*++%286+microsecond%2Fminute%29

			MOV.W		#PFWP,&SYSCFG0			; 3 cycles. Unlock the info section of FRAM, leave program section locked. IN this case, #PFWP is autoaliased to the constant generator register.
			INC.W		0(R11)					; 4 cycles. Increment the mins counter. Note we do not need to do any overflow checking becuase once a day `tsl_next_day` will run and reset this.
			MOV.W		R12,&SYSCFG0	        ; 3 cycles. Lock both info section and program section of FRAM. Using a register for #((PFWP|DFWP) saves one cycle becuase it is not a value in the constant generator.

```

bigjosh, 2024-07-19:
Currently doing the unlock/lock, but should it stay in?

bigjosh, 2024-07-21:
The unlock/lock costs about 3 hours of run time per 100 years, so I say don't over think it and leave it in.

(((2 microseconds) * (200 microamperes)) * ((100 years) / (1 minute))) / (2 microamperes) =
2.92193759 hours

Closed 2024-07-21.

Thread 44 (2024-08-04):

Log current draw when device is first commisioned.

bigjosh, 2024-08-04:
Currently, there is a test on the unit itself that will not let it be commissioned if the current draw is outside a pretty wide band of 1uA-2.4uA, but it would be nice to see the variability and be able to go back and track what a unit was like if a problem ever comes up.

Unfortunately this is difficult to do on the current hardware. We can sort of tell the programmer to power down the TSL and then power it back up and then read the recorded value out of FRAM, but that takes a long time and it a bit flakey.

Better would be to be able to read the current directly out of the energytrace hardware on the programmer, but I was not able to figure out how to do this after about an hour of trying. The protocol to the programmer is not documented. There are closed DLLs available but they are not well documented and when I tried to make energytrace calls into the DLL, it did not work.

Probably the best ways to do this in the future would be (1) reverse engineer the EZ-FET firmware to figure out what commands to send it (or just replace it with new firmware), or (2) add new current measurement hardware onto the programmer.

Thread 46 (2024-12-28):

Replace trigger switch with something more robust

bigjosh, 2024-12-28:
The trigger switch is not well suited for this application. It is pretty flimsy and the arm moves perpendicular to the pin, so when the pin moves it can bend or break the arm. We also had a bad batch of switches that did not close reliably even when the arm moved correctly.

bigjosh, 2024-12-28:
On solution would be to use a magnetically activated switch and have the pin break a magnetic field. Here is a simulation....

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

The switch is at the top, a magnet is at the bottom. You can see that when pin is inserted into the hole on (left side) that it redirects the field away from the switch on top. When the pin is pulled (right side), the fields makes it up to the switch which would close in the presence of the field.

The armatures on the sides could be made from stamped steel. The pin would need to be made from something with high magnetic perativity, so maybe ferritic stainless steel.

The switch could be a reed switch or something solid state like this...

https://www.digikey.com/en/products/detail/coto-technology/RR132-2E33-551/13907128

The solid state version would use an extra ~100nA while in Ready To Launch mode, but maybe more robust to shock than a reed switch would be. Software could mitigate the risk of a false fire due to shock on the reed switch by requiring the circuit to stay solidly closed for some number of milliseconds.

A downside is that it might be possible to trigger the TSL using a big magnet next to it. This whole assembly is buried inside the end cap so that would make it hard to get a magnet close enough, but this would need to be tested to see if it is possible to trigger with a practically sized magnet.

bigjosh, 2024-12-28:
A simpler solution would be to make a physical arm and would get held by the pin. When the pins gets pulled, the arm is released and is pushed by spring action into the contact.

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

This setup has an added benefit that you can visually see if the pin was ever pulled. Although a user could potentially reset it, that would require knowing that this is what is inside, the right hex wrench, and some effort.

The arm could be made from wire or stamped. It should probably be gold plated - or at least the part that makes contact. If it is wire, you'd probably want a couple of bends at the joint so that it could be mounted into holes in the PCB? It probably makes sense for the far end to be constrained, maybe with something like this...

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

https://www.digikey.com/en/products/detail/harwin-inc/S1621-46R/2264455

Not sure what would go on the other end for the arm to make contact with, but could be almost any SMD part with an exposed conductive surface. Maybe a simple existing gold plated part like this?...

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

https://www.digikey.com/en/products/detail/iriso-usa-inc/IPS-4103T-01Y900/14291321

cheewee2000, 2025-01-22:
how's something like this...
(shown in its fabricated state)
So there's no load on the spring while it's getting soldered.
When the cap+pin assembly is joined with the PCB, the pin pushes the spring past the post.
When the pin is pulled, the spring moves back to hit the post.

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

bigjosh, 2025-01-23:
Yea, i hadn't considered the difficulty of soldering while under tension!

This looks like a very cool solution, and super simple to make. We should test some!

I really like the latchy-ness of it, but I *really* want to to latch when the trigger is pulled rather than (or in addition to) when it is loaded so that the pull is *physically* one-time only.  Can you imagine any ways that could work? If not, then this is great!

cheewee2000, 2025-01-24:
updated the post side so the bend is perpendicular to the spring. The spring is longer and less deep so the spring can be more springy.

The way I think of it, the latch gets loaded by the pin when it doesn't have any power, so technically the only time it latches is when the pin is pulled.

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

bigjosh, 2025-01-26:
❤️

1. Can you check to make sure the center of gravity of the bigger piece falls inside the solder pad?
2. Maybe can we add an extra inward bend at the top of the little hook? Just in case the long arm binds against the pin, this will keep the long arm piece from deforming upwards and ensure that- no matter what- the two arms will contact and trigger the TSL.

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

cheewee2000, 2025-01-26:
you read my mind! I was thinking about this while going to sleep last night. I added a bunch of bends to help with pin binding and adjusted for the center of gravity.

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

bigjosh, 2025-01-29:
Looks amazing! Do you think that arm deflection is not too much? Hopefully can be manufactured cheaply even with all those bends! :)

bigjosh, 2025-01-29:
Maybe also try to ask a PCB DFM person if that is going to be easy to place and reflow? Two more bends and there could be alignment tabs on the bottoms.

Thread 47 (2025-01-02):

Maybe ship unit in "load pin" mode rather than ready to launch mode?

bigjosh, 2025-01-02:
To avoid accidental firing, maybe ship the pin separately. Maybe even in a sealed envelope with instructions. The user now needs to....

1. open the envelope
2. stick the pin into the hole
3. wait 3 seconds while the device "arms" itself
4. now they can finally pull the pin when ready to launch it

This should eliminate almost all accidental launches, and associated support requests.

The LCD could ship with a scrolling message like "LOAd PIn to Arm". This would not use additional power compared to the current test pattern - which would still show once the pin was inserted.

bigjosh, 2025-01-02:
Note that this probably would not work well with the current trigger switch, but hopefully could work after #46 .

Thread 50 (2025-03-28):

Add some punched holes to the new trigger switch

bigjosh, 2025-03-28:
To match the holes on the battery holder tabs. I think give a place for excess solder to go?

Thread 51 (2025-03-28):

Add some way to align new trigger switch parts onto pcb

bigjosh, 2025-03-28:
Maybe add some downward bent ears that mate into slots on the PCB? Solder in here will also make the connection much stronger.

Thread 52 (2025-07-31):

Fix battery change in long now mode

bigjosh, 2025-07-31:
Need an extra check on power up to see if we are in long now mode and jump to that.

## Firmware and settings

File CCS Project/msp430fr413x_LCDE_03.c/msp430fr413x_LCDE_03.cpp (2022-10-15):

#include <msp430.h>
#include "i2c_master.h"

#define RV_3032_I2C_ADDR (0b01010001)           // Datasheet 6.6


// *** LCD layout

// These values come straight from pin listing the LCD datasheet combined with the MSP430 LCD memory map
// The 1 bit means that the segment + common attached to that pin will lite.
// The higher L pin is always attached to the A-D segments, the lower L pin is attached to E-G
// Remember that COM numbering for LCD starts at 1 while MSP starts at zero
// And note that the COM order of the E-F-G segments are scrambled!

#define COM0_BIT (0b00000001)
#define COM1_BIT (0b00000010)
#define COM2_BIT (0b00000100)
#define COM3_BIT (0b00001000)

// Low pins
#define SEG_A_COM_BIT (COM0_BIT)
#define SEG_B_COM_BIT (COM1_BIT)
#define SEG_C_COM_BIT (COM2_BIT)
#define SEG_D_COM_BIT (COM3_BIT)

// High pins
#define SEG_E_COM_BIT (COM2_BIT)
#define SEG_F_COM_BIT (COM0_BIT)
#define SEG_G_COM_BIT (COM1_BIT)
#define SEG_S_COM_BIT (COM3_BIT)        // S segments include the low batt, H, M, and S indicators


// Now we draw the digits using the segments as mapped in the LCD datasheet

struct digit_segment_t {
    const char nibble_a_thru_d;     // The COM bits for the digit's A-D segments
    const char nibble_e_thru_g;     // The COM bits for the digit's E-G segments
};


constexpr digit_segment_t digit_segments[] = {

    {SEG_A_COM_BIT | SEG_B_COM_BIT | SEG_C_COM_BIT | SEG_D_COM_BIT , SEG_E_COM_BIT | SEG_F_COM_BIT                  }, // "0"
    {                SEG_B_COM_BIT | SEG_C_COM_BIT                 ,                                               0}, // "1" (no high pin segments lit in the number 1)
    {SEG_A_COM_BIT | SEG_B_COM_BIT |                 SEG_D_COM_BIT , SEG_E_COM_BIT |                 SEG_G_COM_BIT  }, // "2"
    {SEG_A_COM_BIT | SEG_B_COM_BIT | SEG_C_COM_BIT | SEG_D_COM_BIT ,                                 SEG_G_COM_BIT  }, // "3"
    {                SEG_B_COM_BIT | SEG_C_COM_BIT                 ,                 SEG_F_COM_BIT | SEG_G_COM_BIT  }, // "4"
    {SEG_A_COM_BIT |                 SEG_C_COM_BIT | SEG_D_COM_BIT ,                 SEG_F_COM_BIT | SEG_G_COM_BIT  }, // "5"
    {SEG_A_COM_BIT |                 SEG_C_COM_BIT | SEG_D_COM_BIT , SEG_E_COM_BIT | SEG_F_COM_BIT | SEG_G_COM_BIT  }, // "6"
    {SEG_A_COM_BIT | SEG_B_COM_BIT | SEG_C_COM_BIT                 ,                                               0}, // "7"(no high pin segments lit in the number 7)
    {SEG_A_COM_BIT | SEG_B_COM_BIT | SEG_C_COM_BIT | SEG_D_COM_BIT , SEG_E_COM_BIT | SEG_F_COM_BIT | SEG_G_COM_BIT  }, // "8"
    {SEG_A_COM_BIT | SEG_B_COM_BIT | SEG_C_COM_BIT | SEG_D_COM_BIT ,                 SEG_F_COM_BIT | SEG_G_COM_BIT  }, // "9"

};

// This represents a logical digit that we will use to actually display numbers on the screen
// Digit 0 is the rightmost and digit 11 is the leftmost
// LPIN is the name of the pin on the MSP430 that the LCD pin for that digit is connected to.
// Because this is a 4-mux LCD, we need 2 LCD pins for each digit because 2 pins *  4 com lines = 8 segments (7 ofr the 7-segment digit and sometimes one for an indicator)
// These mappings come from our PCB trace layout

struct logical_digit_t {
    const char lpin_a_thru_d;       // The LPIN for segments A-D
    const char lpin_e_thru_g;       // The LPIN for segments E-G
};

constexpr logical_digit_t logical_digits[] {
    { 35 , 34 },        //  0 - corresponds to LCD digit 12 and is the rightmost digit
    { 33 , 32 },        //  1 (LCD 11)
    { 31 , 30 },        //  2 (LCD 10)
    { 29 , 28 },        //  3 {LCD 09)
    { 27 , 26 },        //  4 {LCD 08)
    { 25 , 24 },        //  5 {LCD 07)
    { 21 , 17 },        //  6 (LCD 06)
    { 16 , 15 },        //  7 (LCD 05)
    { 14 , 13 },        //  8 (LCD 04)
    { 12 ,  1 },        //  9 (LCD 03)
    {  2 ,  3 },        // 10 (LCD 02)
    {  4 ,  4 },        // 11 (LCD 01)
    // Rest TBD
};

// Returns the byte address for the specified L-pin
// Assumes MSP430 LCD is in 4-Mux mode
// This mapping comes from the MSP430FR2xx datasheet Fig 17-2

enum nibble_t {LOWER,UPPER};

template <char lpin>
struct lpin_t {
    constexpr static char lcdmem_offset() {
        return (lpin>>1); // Intentionally looses bottom bit since consecutive L-pins share the same memory address (but different nibbles)
    };

    constexpr static nibble_t nibble() {
        return lpin & 0x01 ? UPPER : LOWER;  // Extract which nibble
    }
};

// Write the specified nibble. The other nibble at address a is unchanged.

void set_nibble( char * a , nibble_t nibble_index , char x ) {

    if ( nibble_index == nibble_t::LOWER  ) {

        *a  = (*a & 0b11110000 ) | (x);     // Combine the nibbles and write back to the address

    } else {


        *a  = (*a & 0b00001111 ) | (x<<4);     // Combine the nibbles and write back to the address

    }

}

// Show the digit x at position p
// where p=0 is the rightmost digit

template <char pos, char x>                    // Use template to force everything to compile down to an individualized, optimized function for each pos+x combination
inline void lcd_show() {

    constexpr char nibble_a_thru_d =  digit_segments[x].nibble_a_thru_d;         // Look up which segments on the low pin we need to turn on to draw this digit
    constexpr char nibble_e_thru_g =  digit_segments[x].nibble_e_thru_g;         // Look up which segments on the low pin we need to turn on to draw this digit

    constexpr char lpin_a_thru_d = logical_digits[pos].lpin_a_thru_d;     // Look up the L-pin for the low segment bits of this digit
    constexpr char lpin_e_thru_g = logical_digits[pos].lpin_e_thru_g;     // Look up the L-pin for the high bits of this digit

    constexpr char lcdmem_offset_a_thru_d = (lpin_t< lpin_a_thru_d >::lcdmem_offset()); // Look up the memory address for the low segment bits
    constexpr char lcdmem_offset_e_thru_g = lpin_t< lpin_e_thru_g >::lcdmem_offset(); // Look up the memory address for the high segment bits

    char * lcd_mem_reg = LCDMEM;

    /*
      I know that line above looks dumb, but if you just access LCDMEM directly the compiler does the wrong thing and loads the offset
      into a register rather than the base and this creates many wasted loads (LCDMEM=0x0620)...

            00c4e2:   403F 0010           MOV.W   #0x0010,R15
            00c4e6:   40FF 0060 0620      MOV.B   #0x0060,0x0620(R15)
            00c4ec:   403F 000E           MOV.W   #0x000e,R15
            00c4f0:   40FF 00F2 0620      MOV.B   #0x00f2,0x0620(R15)

      If we load it into a variable first, the compiler then gets wise and uses that as the base..

            00c4e2:   403F 0620           MOV.W   #0x0620,R15
            00c4e6:   40FF 0060 0010      MOV.B   #0x0060,0x0010(R15)
            00c4ec:   40FF 00F2 000E      MOV.B   #0x00f2,0x000e(R15)

     */

    if ( lcdmem_offset_a_thru_d == lcdmem_offset_e_thru_g  ) {

        // If the two L-pins for this digit are in the same memory location, we can update them both with a single byte write
        // Note that the whole process that gets us here is static at compile time, so the whole lcd_show() call will compile down
        // to just a single immediate byte write, which is very efficient.

        const char lpin_a_thru_d_nibble = lpin_t< lpin_a_thru_d >::nibble();

        if ( lpin_a_thru_d_nibble == nibble_t::LOWER  ) {

            // the A-D segments go into the lower nibble
            // the E-G segments go into the upper nibble

            lcd_mem_reg[lcdmem_offset_a_thru_d] = (char) ( nibble_e_thru_g << 4 ) | (nibble_a_thru_d);     // Combine the nibbles, write them to the mem address

        } else {

            // the A-D segments go into the lower nibble
            // the E-G segments go into the upper nibble

            lcd_mem_reg[lcdmem_offset_a_thru_d] = (char) ( nibble_a_thru_d << 4 ) | (nibble_e_thru_g);     // Combine the nibbles, write them to the mem address

        }

    } else {

        // The A-D segments are located on a pin that has a different address than the E-G segments, so we can to manually splice the nibbles into those two addresses

        // Write the a_thru_d nibble to the memory address is lives in

        const nibble_t lpin_a_thru_d_nibble_index = lpin_t< lpin_a_thru_d >::nibble();

        set_nibble( &lcd_mem_reg[lcdmem_offset_a_thru_d] , lpin_a_thru_d_nibble_index , nibble_a_thru_d );


        // Write the e_thru_f nibble to the memory address is lives in

        const nibble_t lpin_e_thru_g_nibble_index = lpin_t< lpin_e_thru_g >::nibble();

        set_nibble( &lcd_mem_reg[lcdmem_offset_e_thru_g] , lpin_e_thru_g_nibble_index , nibble_e_thru_g );

    }

}


volatile unsigned char * Seconds = &BAKMEM0_L;               // Store seconds in the backup RAM module
volatile unsigned char * Minutes = &BAKMEM0_H;               // Store minutes in the backup RAM module
volatile unsigned char * Hours = &BAKMEM1_L;                 // Store hours in the backup RAM module

void Init_GPIO(void);
void Inc_RTC(void);

// test power consumption

int mainx( void )
{
    WDTCTL = WDTPW | WDTHOLD;                               // Stop watchdog timer

    // Disable the GPIO power-on default high-impedance mode
    // to activate previously configured port settings
    PM5CTL0 &= ~LOCKLPM5;

    // Configure all GPIO to Output Low
    P1OUT = 0x00;P2OUT = 0x00;P3OUT = 0x00;P4OUT = 0x00;
    P5OUT = 0x00;P6OUT = 0x00;P7OUT = 0x00;P8OUT = 0x00;

    P1DIR = 0xFF;P2DIR = 0xFF;P3DIR = 0xFF;P4DIR = 0xFF;
    P5DIR = 0xFF;P6DIR = 0xFF;P7DIR = 0xFF;P8DIR = 0xFF;

    PMMCTL0_H = PMMPW_H;                                // Open PMM Registers for write
    PMMCTL0_L |= PMMREGOFF_L;                           // and set PMMREGOFF
    __bis_SR_register(LPM3_bits | GIE);                 // Re-enter LPM3.5

    return 0;

}

int main( void )
{
    WDTCTL = WDTPW | WDTHOLD;                               // Stop watchdog timer
    if (SYSRSTIV == SYSRSTIV_LPM5WU)                        // If LPM3.5 wakeup
    {


        /*
         * When an overflow occurs, the RTCIFG bit in the RTCCTL register is set until it is cleared by a read of the
         * RTCIV register. At the same time, an interrupt is submitted to the CPU for post-processing, if the RTCIE
         * bit in the RTCCTL register is set. Reading RTCIV register clears the interrupt flag.
         */

        RTCIV; // Clear RTC interrupt. If we do not do this then the RTC ISR will be needlessly called when drop into LPM3.5


        // toggle low power waveform so we can see if it is visible (turns out only visible from wide viewing angles)
        // Divide by 1 (so CLK will be 10Khz), Very Low Osc, Turn on LCD, 4-mux selected (LCD4MUX also includes LCDSON), Low power waveform
        //LCDCTL0 ^= LCDLP ;

        switch (*Seconds) {

            case 0:
                *Seconds=1;
                lcd_show< 0,1>();
                break;

            case 1:
                *Seconds=2;
                lcd_show< 0,2>();
                break;

            case 2:
                *Seconds=3;
                lcd_show< 0,3>();
                break;

            case 3:
                *Seconds=4;
                lcd_show< 0,4>();
                break;

            case 4:
                *Seconds=5;
                lcd_show< 0,5>();
                break;

            case 5:
                *Seconds=6;
                lcd_show< 0,6>();
                break;

            case 6:
                *Seconds=7;
                lcd_show< 0,7>();
                break;

            case 7:
                *Seconds=8;
                lcd_show< 0,8>();
                break;

            case 8:
                *Seconds=9;
                lcd_show< 0,9>();
                break;

            case 9:
                *Seconds=0;
                lcd_show< 0,0>();
                break;


            default:
                *Seconds=0;
                lcd_show< 0,0>();
                break;

        }


        PMMCTL0_H = PMMPW_H;                                // Open PMM Registers for write
        PMMCTL0_L |= PMMREGOFF_L;                           // and set PMMREGOFF
        __bis_SR_register(LPM3_bits | GIE);                 // Re-enter LPM3.5

        // We never get here because LPM3.5 reboots on wake


    }
    else
    {
        // Initialize GPIO pins for low power
        Init_GPIO();

        // Disable the GPIO power-on default high-impedance mode
        // to activate previously configured port settings
        PM5CTL0 &= ~LOCKLPM5;

        /*
            // This code is for testing LCD individual segments, it outputs out of phase square waves on MSP430 pins 1 and 2.
            // Connect one to SEG and one to COM and the segment should lite.
            while (1) {
                P7OUT = 0b10101010;
                __delay_cycles( 10000 );    // 100Hz
                P7OUT = 0b01010101;
                __delay_cycles( 10000 );    // 100Hz
            }
        */

        *Seconds = 5;                                       // Set initial time to 12:00:00
        *Minutes = 0;
        *Hours = 10;


/*

        // Configure XT1 oscillator
        P4SEL0 |= BIT1 | BIT2;                              // P4.2~P4.1: crystal pins
        do
        {
            CSCTL7 &= ~(XT1OFFG | DCOFFG);                  // Clear XT1 and DCO fault flag
            SFRIFG1 &= ~OFIFG;
        } while (SFRIFG1 & OFIFG);                           // Test oscillator fault flag

        CSCTL6 = (CSCTL6 & ~(XT1DRIVE_3)) | XT1DRIVE_2;     // Higher drive strength and current consumption for XT1 oscillator

        RTCCTL = RTCSS__XT1CLK ;                    // Initialize RTC to use XT1 and enable RTC interrupt



*/

        //RTCCTL = RTCSS__VLOCLK ;                    // Initialize RTC to use VLO clock

        // Configure LCD pins
        SYSCFG2 |= LCDPCTL;                                 // LCD R13/R23/R33/LCDCAP0/LCDCAP1 pins enabled

        // TODO: We can make a template to compute these from logical_digits
        LCDPCTL0 = 0b1111111111111111;  // LCD pins L15-L00, 1=enabled
        LCDPCTL1 = 0b1111111111111111;  // LCD pins L31-L16, 1=enabled
        LCDPCTL2 = 0b0000000000001111;  // LCD pins L37-L32, 1=enabled

        // LCDCTL0 = LCDSSEL_0 | LCDDIV_7;                     // flcd ref freq is xtclk

        LCDMEMCTL |= LCDCLRM;                               // Clear LCD memory command (executed one shot)

        // TODO: Try different clocks and dividers

        // Divide by 2 (so CLK will be 10KHz/2= 5KHz), Very Low Osc, Turn on LCD, 4-mux selected (LCD4MUX also includes LCDSON)
        // Note this has a bit of a flicker
        //LCDCTL0 = LCDDIV_2 | LCDSSEL__VLOCLK | LCD4MUX | LCDSON | LCDON  ;

        // TODO: Try different clocks and dividers
        // Divide by 1 (so CLK will be 10Khz), Very Low Osc, Turn on LCD, 4-mux selected (LCD4MUX also includes LCDSON)
        //LCDCTL0 = LCDDIV_1 | LCDSSEL__VLOCLK | LCD4MUX | LCDSON | LCDON  ;

        // Divide by 1 (so CLK will be 10Khz), Very Low Osc, Turn on LCD, 4-mux selected (LCD4MUX also includes LCDSON), Low power saveform
        LCDCTL0 = LCDDIV_1 | LCDSSEL__VLOCLK | LCD4MUX | LCDSON | LCDON | LCDLP ;



/*
        // Divide by 32 (so CLK will be 32768/32 = ~1KHz), Very Low Osc, Turn on LCD, 4-mux selected (LCD4MUX also includes LCDSON)
        LCDCTL0 = LCDDIV_7 | LCDSSEL__XTCLK | LCD4MUX | LCDSON | LCDON  ;
*/


        // LCD Operation - Mode 3, internal 3.08v, charge pump 256Hz, 3.4uA
        //LCDVCTL = LCDCPEN | LCDREFEN | VLCD_6 | (LCDCPFSEL0 | LCDCPFSEL1 | LCDCPFSEL2 | LCDCPFSEL3);

        // LCD Operation - internal V1 regulator=3.32v , charge pump 256Hz
        // LCDVCTL = LCDCPEN | LCDREFEN | VLCD_12 | (LCDCPFSEL0 | LCDCPFSEL1 | LCDCPFSEL2 | LCDCPFSEL3);


        // LCD Operation - Pin R33 is connected to external Vcc, charge pump 256Hz, 1.7uA
        //LCDVCTL = LCDCPEN | LCDSELVDD | (LCDCPFSEL0 | LCDCPFSEL1 | LCDCPFSEL2 | LCDCPFSEL3);


        // LCD Operation - Pin R33 is connected to internal Vcc, no charge pump
        //LCDVCTL = LCDSELVDD;


        // LCD Operation - Pin R33 is connected to external V1, charge pump 256Hz, 1.7uA, Low Power Waveform
        LCDVCTL = LCDCPEN | (LCDCPFSEL0 | LCDCPFSEL1 | LCDCPFSEL2 | LCDCPFSEL3) | LCDLP;

/*
        // For MSP430FR4133-EXP
         *
        LCDCSSEL0 = 0x000F;                                 // Configure COMs and SEGs
        LCDCSSEL1 = 0x0000;                                 // L0, L1, L2, L3: COM pins
        LCDCSSEL2 = 0x0000;

        LCDM0 = 0x21;                                       // L0 = COM0, L1 = COM1
        LCDM1 = 0x84;                                       // L2 = COM2, L3 = COM3
*/

        // For TSL
        // Configure COMs and SEGs
        LCDCSSEL0 = LCDCSS8 | LCDCSS9 | LCDCSS10 | LCDCSS11 ;     // L8-L11 are the 4 COM pins
        LCDCSSEL1 = 0x0000;
        LCDCSSEL2 = 0x0000;

        // L08 = MSP_COM3 = LCD_COM3
        // L09 = MSP_COM2 = LCD_COM2
        // L10 = MSP_COM1 = LCD_COM1
        // L11 = MSP_COM0 = LCD_COM0

        // Once we have selected the COM lines above, we have to connect them in the LCD memory. See Figure 17-2 in MSP430FR4x family guide.
        // Each nibble in the LCDMx regs holds 4 bits connecting the L pin to one of the 4 COM lines (two L pins per reg)

        LCDM4 =  0b01001000;  // L09=MSP_COM2  L08=MSP_COM3
        LCDM5 =  0b00010010;  // L10=MSP_COM0  L11=MSP_COM1


        // Set up RTC



        RTCMOD = 10000;                                     // Set RTC modulo to 1000 to trigger interrupt each second on 10Khz VLO clock. This will get loaded into the shadow register on next trigger or reset

        RTCCTL |=  RTCSR;                    // reset RTC which will load overflow value into shadow reg and reset the counter to 0,  and generate RTC interrupt

        RTCIV;                      // Clear any pending RTC interrupt

        // TRY THIS, MUST ALSO ADJUST LCDSEL
        // Use VLO instead of XTAL
        RTCCTL = RTCSS__VLOCLK | RTCIE;                    // Initialize RTC to use Very Low Oscillator and enable RTC interrupt on rollovert

/*
        lcd_show< 0,6>();
        P1DIR |= 1<<3;

        while (1) {

            P1OUT |= 1<<3;
            __delay_cycles(100);
            P1OUT &= ~(1<<3);
            __delay_cycles(100);

        }
*/

        i2c_init();

        uint8_t save_flags_reg;

        while (1) {

            i2c_read( RV_3032_I2C_ADDR , 0x01 , &save_flags_reg , 1 );

        }


        lcd_show< 0,0>();
        lcd_show< 1,1>();
        lcd_show< 2,2>();
        lcd_show< 3,3>();
        lcd_show< 4,4>();
        lcd_show< 5,5>();
        lcd_show< 6,6>();
        lcd_show< 7,7>();
        lcd_show< 8,8>();
        lcd_show< 9,9>();
        lcd_show<10,0>();
        lcd_show<11,1>();


        // Go into LPM3.5 sleep
        PMMCTL0_H = PMMPW_H;                                // Open PMM Registers for write
        PMMCTL0_L |= PMMREGOFF_L;                           // and set PMMREGOFF
        __bis_SR_register(LPM3_bits | GIE);                 // Re-enter LPM3.5

        /*
        PMMCTL0_H = PMMPW_H;                                // Open PMM Registers for write
        PMMCTL0_L = PMMREGOFF_L | SVSHE;                   // and set PMMREGOFF (go into a x.5 mode on next sleep) and disable low voltage monitor

        __bis_SR_register(LPM3_bits | GIE);                 // Enter LPM3.5
        __no_operation();                                   // For debugger
         */


    }
}

#pragma vector = RTC_VECTOR

__interrupt void RTC_ISR(void) {

    // Currently we never make it here in LPM3.5

    //RTCIV;
    //__no_operation();                                   // For debugger


    //(LCDMEM[pos4])++;//= digit[4];

    /*

    (LCDMEM[pos2])= digit[1];


    PMMCTL0_H = PMMPW_H;                                // Open PMM Registers for write
    PMMCTL0_L |= PMMREGOFF_L;                           // and set PMMREGOFF
    __bis_SR_register(LPM3_bits | GIE);                 // Re-enter LPM3.5

    (LCDMEM[pos2])= digit[6];

    */

    /*

    Inc_RTC();

    (LCDMEM[pos4]) = digit[4];

    PMMCTL0_H = PMMPW_H;                                // Open PMM Registers for write
    PMMCTL0_L |= PMMREGOFF_L;                           // and set PMMREGOFF
    __bis_SR_register(LPM3_bits | GIE);                 // Re-enter LPM3.5
*/
}

void Init_GPIO()
{
    // Configure all GPIO to Output Low
    P1OUT = 0x00;P2OUT = 0x00;P3OUT = 0x00;P4OUT = 0x00;
    P5OUT = 0x00;P6OUT = 0x00;P7OUT = 0x00;P8OUT = 0x00;

    P1DIR = 0xFF;P2DIR = 0xFF;P3DIR = 0xFF;P4DIR = 0xFF;
    P5DIR = 0xFF;P6DIR = 0xFF;P7DIR = 0xFF;P8DIR = 0xFF;
}

// Real clock function
void Inc_RTC()
{

/*
    LCDMEM[pos6]++;
    return;
    */

    // Deal with second
    (*Seconds)++;


/*
    if ((*Seconds & 0x01) == 0x01) {
        LCDMEM[pos6] = 0x00;
        LCDMEM[pos5] = 0x00;
        LCDMEM[pos4] = 0x00;
        LCDMEM[pos3] = 0x00;

    } else {
        LCDMEM[pos6] = digit[2];
    }
    return;
*/

    if (*Seconds == 60) {
        *Seconds = 0;
    }

    /*
    LCDMEM[pos0] = digit[(*Seconds) % 10];
    LCDMEM[pos1] = digit[(*Seconds) / 10];
    */
/*

    // Deal with minute
    if ((*Seconds) == 0) 
    {
        (*Minutes)++;
        (*Minutes) %= 60;
        LCDMEM[pos4] = digit[(*Minutes) % 10];

        if (((*Minutes) % 10) == 0)
        {
            LCDMEM[pos3] = digit[(*Minutes) / 10];
        }


        LCDMEM[pos3] = digit[(*Minutes) / 10];


        // Deal with hour
        if ((*Minutes) == 0)
        {
            (*Hours)++;
            (*Hours) %= 24;
            LCDMEM[pos2] = digit[(*Hours) % 10];
            if (((*Hours) % 10) == 0)
            {
                LCDMEM[pos1] = digit[(*Hours) / 10];
            }
        }
    }
*/
}

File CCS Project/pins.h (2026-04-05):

/*
 * pins.h
 *
 * Defines all of the pins we are using
 *
 *  Created on: Oct 15, 2022
 *      Author: josh
 */

#ifndef PINS_H_
#define PINS_H_

// IMPORTANT: Our ASM code blindly overwrites P1IFG so the RTC clkout should be the only interrupt in this register.

// Connected to the RV3203 INT pin which is open collector on RV3032 side

#define RV3032_INT_PREN   P1REN
#define RV3032_INT_PDIR   P1DIR
#define RV3032_INT_POUT   P1OUT
#define RV3032_INT_PIN    P1IN
#define RV3032_INT_PIE    P1IE          // Interrupt enable
#define RV3032_INT_PIV    P1IV          // Interrupt vector (read this to get which pin caused interrupt, reading clears highest pending)
#define RV3032_INT_PIFG   P1IFG         // Interrupt flag (bit 1 for each pin that interrupted)
#define RV3032_INT_PIES   P1IES         // Interrupt Edge Select (0=low-to-high 1=high-to-low)

#define RV3032_INT_B (4)       // Bit


// Connected to the RV3203 CLKOUT pin

#define RV3032_CLKOUT_PREN   P1REN
#define RV3032_CLKOUT_PDIR   P1DIR
#define RV3032_CLKOUT_POUT   P1OUT
#define RV3032_CLKOUT_PIN    P1IN
#define RV3032_CLKOUT_PIE    P1IE          // Interrupt enable
#define RV3032_CLKOUT_PIV    P1IV          // Interrupt vector (read this to get which pin caused interrupt, reading clears highest pending)
#define RV3032_CLKOUT_PIFG   P1IFG         // Interrupt flag (bit 1 for each pin that interrupted)
#define RV3032_CLKOUT_PIES   P1IES         // Interrupt Edge Select (0=low-to-high 1=high-to-low)
#define RV3032_CLKOUT_VECTOR PORT1_VECTOR  // ISR vector

#define RV3032_CLKOUT_VECTOR_RAM ram_vector_PORT1  // The RAM vector called when this pin ticks

#define RV3032_CLKOUT_B (1)       // Bit

// I2C data connection to RV3032 on pin P1.5 which is pin number 23 on MSP430

#define I2C_DTA_PREN P1REN
#define I2C_DTA_PDIR P1DIR
#define I2C_DTA_POUT P1OUT
#define I2C_DTA_PIN  P1IN
#define I2C_DTA_B (5)       // Bit

// I2C clock connection to RV3032 on pin P1.0 which is pin number 28 on MSP430

#define I2C_CLK_PREN P1REN
#define I2C_CLK_PDIR P1DIR
#define I2C_CLK_POUT P1OUT
#define I2C_CLK_PIN  P1IN

#define I2C_CLK_B (0)


// RV3032 Event input pin is hardwired to ground to avoid having it float during battery changes (uses lots of power)


// Power the RV3032 on pin P1.2 which is pin number 26 on MSP430

#define RV3032_VCC_PREN P1REN
#define RV3032_VCC_PDIR P1DIR
#define RV3032_VCC_POUT P1OUT
#define RV3032_VCC_PIN  P1IN

#define RV3032_VCC_B (2)

// Ground the RV3032 on pin P1.3 which is pin number 23 on MSP430
// Having the RV30332 ground come from the MCU should give extra isolation since it runs though the MSP decoupling cap
// and this also makes sure their grounds are close together.

#define RV3032_GND_PREN P1REN
#define RV3032_GND_PDIR P1DIR
#define RV3032_GND_POUT P1OUT
#define RV3032_GND_PIN  P1IN

#define RV3032_GND_B (3)



// Trigger switch pin P2.1 which is pin number 41 on MSP430. This pin uses ISR vector

#define TRIGGER_PREN   P2REN
#define TRIGGER_PDIR   P2DIR
#define TRIGGER_POUT   P2OUT
#define TRIGGER_PIN    P2IN
#define TRIGGER_PIE    P2IE           // Interrupt enable
#define TRIGGER_PIV    P2IV           // Interrupt vector (read this to get which pin caused interrupt, reading clears highest pending)
#define TRIGGER_PIFG   P2IFG          // Interrupt flag (bit 1 for each pin that interrupted)
#define TRIGGER_PIES   P2IES          // Interrupt Edge Select (0=low-to-high 1=high-to-low)
#define TRIGGER_VECTOR PORT2_VECTOR   // ISR vector

#define TRIGGER_VECTOR_RAM ram_vector_PORT2  // The RAM vector called when this pin ticks

#define TRIGGER_B (1)



// Debug out A on pin P1.7 which is pin number 21 on MSP430

#define DEBUGA_PREN P1REN
#define DEBUGA_PDIR P1DIR
#define DEBUGA_POUT P1OUT
#define DEBUGA_PIN  P1IN

#define DEBUGA_B (7)


// Debug out B on pin P1.6 which is pin number 22 on MSP430

#define DEBUGB_PREN P1REN
#define DEBUGB_PDIR P1DIR
#define DEBUGB_POUT P1OUT
#define DEBUGB_PIN  P1IN

#define DEBUGB_B (6)


// Q1 Top flash LED

#define Q1_TOP_LED_PREN P4REN
#define Q1_TOP_LED_PDIR P4DIR
#define Q1_TOP_LED_POUT P4OUT
#define Q1_TOP_LED_PIN  P4IN
#define Q1_TOP_LED_B (0)       // Bit

// Q2 Bottom flash LED

#define Q2_BOT_LED_PREN P4REN
#define Q2_BOT_LED_PDIR P4DIR
#define Q2_BOT_LED_POUT P4OUT
#define Q2_BOT_LED_PIN  P4IN
#define Q2_BOT_LED_B (1)        // Bit


// TSP voltage regulator

#define TSP_ENABLE_PREN P7REN
#define TSP_ENABLE_PDIR P7DIR
#define TSP_ENABLE_POUT P7OUT
#define TSP_ENABLE_PIN  P7IN
#define TSP_ENABLE_B (0)       // Bit

#define TSP_IN_PREN P4REN
#define TSP_IN_PDIR P4DIR
#define TSP_IN_POUT P4OUT
#define TSP_IN_PIN  P4IN
#define TSP_IN_B (2)       // Bit




#endif /* PINS_H_ */

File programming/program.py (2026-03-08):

# use this script to program new units
# sorry it is so ugly, but i wanted it to be pythonic

import subprocess
import time
import shutil
import hashlib
import tempfile
import os
import uuid

# we use this to make it possible to portably read a single keypress
import getch

# for logging to the google sheet
import addrow

#MSPFlasher executable name
mspflasher_name = "MSP430Flasher"

#env variables
logscript_url = os.environ.get( "tsl_logscript" , "" ).strip()
logscript_enabled = ( logscript_url != "" ) and ( logscript_url.lower() != "none" )

if logscript_enabled:
    print( f"Logging to google app script at {logscript_url}" )
else:
    print( "Logging disabled." )

#locate MSP430Flasher executable
mspflasher_exec = shutil.which( mspflasher_name )
#check that it was found
if mspflasher_exec is None:
    raise Exception("MSPFlasher executable must be in search path")  

print( f"Using MSPFlasher executable at {mspflasher_exec}" )

machine_uuid_string = str(uuid.UUID(int=uuid.getnode()))
print( f"Machine UUID: {machine_uuid_string}" )


def print_bytes_as_table(data):
    for i in range(0, len(data), 16):
        line = data[i:i+16]
        hex_line = ' '.join(f'{b:02X}' for b in line)
        print(f'{i:04X}: {hex_line}')

""" Read in a firmware image file in TI txt format and return a byte array """
def decode_titxt(titxt_data):

    #lines = titxt_data.decode('utf-8')    

    lines = titxt_data.splitlines()

    # Remove any leading or trailing whitespace from each line
    lines = [line.strip() for line in lines]

    # Remove empty lines and comments
    lines = [line for line in lines if line and not line.startswith('@') and not line.startswith('q')]

    # Concatenate the data fields into a single string
    data_string = ''.join(lines)

    # Convert the hexadecimal string to a byte array
    data_bytes = bytes.fromhex(data_string)

    return data_bytes   


    # Lets grab the UUID and device info from the device descripto dump and make them into a serial number
    # these are in TI HEX format so we have to throw away the first line and then strip out all whitespace from the second line to get a clean hex digit string

def get_ddid_from_file( dd_file_name ):
    with open(dd_file_name,"r") as f:
        # throw away the address line
        f.readline()
                
        # grab first and second line and strip all whitespace
        line1 = f.readline()
        line2 = f.readline()
        
        # now line1 is bytes 0x1a00-0x1a0f of the device desriptor table as ascii hex digits
        # now line2 is bytes 0x1a10-0x1a11 of the device desriptor table as ascii hex digits
        
        # make all the read bytes into a single linear array
        dd_hex_bytes = (line1+line2).split()

        # note in all the extractions below that in Python string slices, the end index is one past the index               
                                        
        # device info is 0x1a04-0x1a07 (4 bytes)
        device_info =  dd_hex_bytes[ 0x04 : 0x08 ]

        # Lot waffer ID 0x1a0a-0x1a0d
        lot_waffer = dd_hex_bytes[ 0x0a : 0x0e ]
        
        # Die X pos 0x1a0e-0x1a0f               
        die_x_pos =  dd_hex_bytes[ 0x0e : 0x10 ]
        
        # Die Y pos 0x1a10-0x1a11
        die_y_pos = dd_hex_bytes[ 0x10 : 0x12 ]
        
        # I know this is ugly, but seems to be the phythonic way to join these all into a string with no seporator.
        # Do you know a better way? 
        device_uuid = "".join(device_info+lot_waffer+die_x_pos+die_y_pos)

        return device_uuid

# enter interactive TSL programming loop
def program_loop():

    # firmware in TI hex format
    firmware_file_name = "tsl-calibre-msp.txt"

    # load the firmware file into memory variable `data`

    print(f"Loading {firmware_file_name} into memory...")   
    with open(firmware_file_name, 'rb') as file:
        data = file.read()

    # cacluate the hash of the firmware file
    firmware_hash = hashlib.md5(data).hexdigest()

    print( f"Firmware hash is {firmware_hash}\n")

    # repeat programming cycle until user quits or error
    while True: 
        
        #clear any buffered keypresses
        while ( getch.key_available() ):
            getch.getch()


        # wait for user to start programming cycle
        print("\rPress [spacebar] to start programming cycle, any other key to exit...")

        while ( not getch.key_available() ):
            pass

        key = getch.getch()

        if key != ' ':
            print(f"Exited by user, key = {key}")
            exit(0)

        print("Programming cycle started.")
                
        # Create a temp directory for the files we are creating, then create temp files for the firmware image (will auto delete everything when pass finished)
        with tempfile.TemporaryDirectory() as tempdir:
            
            # first we create a firmware image to write to FRAM. We do this by combining a timestamp with the compiled firmware 

            print("Creating firmware image...")
            image_file_name = os.path.join( tempdir , 'image.txt' )    
            with open( image_file_name ,'wb') as wfd:
            
                # get the current GMT time
                t = time.gmtime()
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

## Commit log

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2022-10-18 Full running with static LCD 1.2uA @ 3V
    Sometimes gets messed up after programming and requires a power cycle?
2022-10-18 OK now works consistently 1.7uA stupid compiler setting
    "Enable ultra low power debug" *must* be set off or you are going to get sometimes 200uA extra current after a download! Argh!!!!!!
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2022-10-18 Ticks successfully at 2.3uA @ 3V with RV3203 connected via INT line to pullup
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2022-10-18 Init hardware folder with old ATXMEGA version of the PCB
    [BOM.csv, ESE18L61D.step, ESE18L61D.stp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]
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2022-10-19 Visually clean up TEST and RST lines around battery terminal, get rid of a Vcc loop over there.
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2022-10-26 Update LCD code to match new PCB layout. Add flash LED pins.
2022-10-27 Everything working with PCB running about 2.5uA for RTC driven blink pattern
2022-10-28 Flash and trigger pin working
    Currently counts digit 8 based on INT pin and digit 7 based on trigger pin.
2022-10-28 Make LCD holes bigger and oblong
    Current LCD pins don't fit right, so hopefully this will be more accommodating, although it is ugly and leaves less pad for soldering. Closes #1
2022-10-31 Everything running nicely with 3.0V regulator, pulling 2.2uA for blink display.
    Fixed some problem where i2cread was not working, but not sure why.
    [i2c_master.cpp, pins.h, tsl-calibre-msp.cpp]
2022-10-31 Hardwire RV3032 EVI pin to ground to avoid floating during battery changes`
    Since i2c pins are already covered by #12 this change can close #11
    [pins.h, tsl-calibre-msp.cpp]
2022-11-01 Fully functional except for recovery from a battery change
    Still tons of optimization possible, but the *most* we could theoretically save if we optimized out all software is about 01.uA!
2022-11-05 Startup state machine done
    All time-based until the actual trigger pull to avoid races and bouncing.
    [pins.h, tsl-calibre-msp.cpp]
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2022-12-06 Graphics updates by TL
    [keystone-PN1024.STEP]
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2022-12-06 Re-org LCD pins to...
    1. make room on P2 for the trigger pin connection so it can be ISR driven (ISR only on P1 and P2)
    2. make all visible traces symmetric
    3. move as many digits as possible to be in the same word in LCD memory for efficient updating
2022-12-06 Move trigger pin to P2 port so it can have dedicated ISR
    Makes this ever so slightly more efficient during ready to launch mode since we will not need to test the trigger pin bit. Hey, every cycle counts!
2022-12-14 Clean up glitch race on trigger pin ISR, add a tiny glitch filter. Closes #17
    [tsl-calibre-msp.cpp]
2022-12-15 Move RV3032 ground to an MSP IO pin. Add copper to the topside end tap. Clean up some of the aesthetics of the LCD traces.
    Running the RV3032 ground though the IO pin should help keep them floating and give some noise resistance.
    [pins.h, tsl-calibre-msp.cpp]
2022-12-15 Rename confusing TRIGGER_SWITCH `trigger pin` to just TRIGGER and `trigger`. Delete unused LPMx.5 stuff.
2022-12-15 Fix wrongly defined debug pin, fix wrongly enabled LCD pin, lots of cleanup.
    [pins.h, tsl-calibre-msp.cpp]
2022-12-16 Added instrumentation to see how long RTC backup lasts for.
    Shows a 50 on the screen if RTC was still running at last power up, or 10 if not.
2022-12-17 Update BOM links for capacitors and transistors to current parts
    [BOM.csv]
2022-12-17 Make new `assembly` folder for stuff to get included with PCBA order
    [BOM.csv]
2022-12-17 Add test points to PCB.
    Who knows, might need them some day?
2023-01-19 Merge in all changes from rtc-add-diode except keep current PCB layout
    Adding the diode was not worth it and time is of the essence, so keep last produced PCB design. We loose the very nice serial programming pins, but can always add these later.
    [pins.h, tsl-calibre-msp.cpp]
2023-01-20 Move timekeeping signal from ~INT pin to CLKOUT pin
    Turns out that the periodic timer uses 0.2uA so we switch to CLKOUT@1Hz and now total power down around 1.8uA.
2023-01-21 Switch to SMALL memory model to avoid costly CALLA stuff.
    Why would it even let you use LARGE memory model with a chip that only has 16K FRAM?
    [tsl-calibre-msp.cpp]
2023-01-27 Fixed new typo into RTC power reg that broke backup!
    Also switched backup charge to be though a 12K resistor to minimized current surge when the RTC is powered up.
    [tsl-calibre-msp.cpp]
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2023-01-27 Added copper dots to mark pin #1 for the two chips
    Makes it so you can still see which pin even with no silk.
2023-01-27 Move flash LEDs to top side of PCB
    Also added 3D model for LEDs
    [62-217D.STEP]
2023-01-27 Add 3D models
    [Ceramic_Capacitor_0603_h32mil (1).step, Ceramic_Capacitor_0805_h50mil.step, ESE18L61D.step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]
2023-01-31 Feature complete. Better error messages.
    [tsl-calibre-msp.cpp]
2023-02-02 Update BOM to fix part numbers for U1 and U2
    [BOM.csv]
2023-02-02 Update BOM to despecify RV-3032-C7 part number (any will work)
    [BOM.csv]
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2023-02-06 Move ASM ISRs into RAM to save power
    Now seconds update ISR completes in 14.3us and squiggle in 44.8us.
    RAM is faster but makes me nervous. Maybe RAM is more susceptible to cosmic rays over the centuries? I guess we will see.
2023-02-11 Feature complete and optimized. Only thing missing is multi-century battery change logic.
    Should also check once and for all if turning off the FRAM controller saves power.
    [tsl-calibre-msp.cpp]
2023-02-12 Final optimize RTL animation to get rid of branch and a couple of MOVs, dropping a few dozen cycles
    This is it for this code, I do not think it is possible to further optimize it without changing the layout on the PCB.
    Comes in at 1.2-1.3uA, total ISR time only 41us (no branching, so always constant) to update the entire display.
2023-02-16 Add T1 test pads to BOM as "DO NOT PLACE"
    [BOM.csv]
2023-03-15 Added ACID FRAM record abstraction so we can recover from power loss at the moment we are updating the year counter.
    Not complete implementation and not tested, but framework is here.
    Also first skeleton of the programming stuff.
2023-03-21 Fleshed out all the century book keeping stuff. Code complete, but untested.
    So much complexity to deal with (1) the fact the the RTC rolls over every century, and (2) it is possible for the user to change the battery exactly at the moment the century rolls, so we would other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
2023-03-23 UNTESTED! Fleshed out all the century book keeping stuff. Code complete, but untested.
    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
2023-03-23 Update BOM to fix incorrect part number for U3
    Was TPS7A012PDBVR which is WRONG
    Fixed to TPS7A0230PDBVR which is CORRECT
    Yikes!
    [BOM.csv]
2023-04-03 First blush of working programming.
    Correctly programs a unit, but we still need to add in stuff to save info to the databases for record keeping.
    [program.py]
2023-04-21 Update `program.py` to workaround an MSPFlasher issue
    MSPFlasher seems to silently ignore the second read command in a sequence, so we instead now do one big read command that dumps the full range that includes all the bytes we need rather than dumping the specific smaller ranges. Then we parse out the bytes we need from the resulting dump. More complicated and dumps more bytes than we need, but works.
    [program.py]
2023-04-25 Disable `RESET` pin between programming
    Some units programmed at CW&T seemed to have bad chips, so maybe this reset pin is messing up the chip when it contacts the `Vcc` pin as the PCB is slid into the programming jig? Disabling the `RESET` does not seem to cause any problems with the chip booting up after programming, so mind as well try this and see if it has an effect.
    [program.py]
2023-05-02 Positively turn on and enable the TSP voltage regulator pins.
    Does not change operation, but is correct. Before these pins were still in input mode, but the currents are so low it does not matter.
    [tsl-calibre-msp.cpp]
2023-05-17 Added new `dump` command to `program.py`
    Will list all the info in the user data and also looks up the deviceID in Airtable and lists all programming events.
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2024-07-10 Remove RTC backup CAP from BOM
    Still need to update firmware to continuously track elapsed time as per #29.
    [BOM.csv]
2024-07-10 Add 10K resistor to VBAT as per microsemi
    I am skeptical this is needed, but it is cheap and low risk so we will add it just to be safe. Must make sure to turn off VBAT in the firmware as per #35.
    [BOM.csv]
2024-07-10 Update schematic to match replacement of C2 with 10K RES
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2024-07-16 Disable backup switchover in the RTC config
    Count power usage:
    Prev firmware with backup enabled and cap on PCB | 2.0uA
    New firmware with cap on PCB (should not happen) | 2.0uA
    New firmware with 10K resistor in place C2 | 2.0uA
    ...and the failure case where old firmware gets on new PCB | 120uA
    So we need to make sure that old firmware does not get on new PCBs. It should get caught during commissioning because the power will not be able to ride the time between programming and battery insertion.
    [tsl-calibre-msp.cpp]
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2024-07-23 Fixed a *very* edge case where...
    ... we lose power in the middle of an update that updates the day.
    [tsl-calibre-msp.cpp]
2024-07-25 Power down currrent measurement working using the internal RTC
    Now to switch to the RV3032 so we can test the CLKOUT trace for shorts also.
    [tsl-calibre-msp.cpp]
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2024-08-04 Switch the unit programming log from AirTable to a google sheets web-app
    Airtable was a hassle and only lets you have 500 records now. A Google sheet can have over a million rows, so should not be an issue for a while.
    [addrow.py, program.py]
2024-08-04 Fix typo in comment
    [addrow.py]
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2024-12-28 Relax limit for `AMPS LOW` error
    Empirically it looks like some new boards can use less than 1.6uA in a cold, dry environment. This update moves the minimum down from ~1.6uA to ~1.47uA so these boards will pass.
    [tsl-calibre-msp.cpp]
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2025-01-30 Fix handling when relays and logging are *not* enabled.
    [program.py]
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2026-02-02 LCD display bug
    lcd_show_lo_volt_message() writes to position 2 twice, overwriting the thousands digit with the hundreds digit. In pratice this had no functional impact since (1) it only effects what is printed in the diagnostic, (2) the top digit is not relevant if this message ever happened, (3) this message has never happened.
    But still should be correct!
    [tsl-calibre-msp.cpp]
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2026-04-05 Remove on-board power test - factory fixture now does it at programming time..
    [tsl-calibre-msp.cpp]
2026-04-07 Streamline startup for the coming-soon Pi Pico programming fixture
    Take stuff out of the startup we do not need for the first current test- like precomputing the digit arrays.
    They updated the datasheets for the RV3032 so we can narrow the startup delay here too.
    [tsl-calibre-msp.cpp]
2026-04-08 No blink in testing only mode
    Make it easier for programming fixture to measure power.
    [tsl-calibre-msp.cpp]
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2026-10-12 Change R1 to RES_0603 in schematic to match PCB
    The PCB was switched to an 0603 footprint for R1 in f2d2967 but the
    schematic still carried RES_0805_N / RES_0805_INCH, so a Renew Design
    from Schematic would have reverted the board to 0805. R1 is now
    RES_0603_N with pattern RES_0603_INCH from res_chip_inch, identical to
    what the PCB already uses. DipTrace also dropped unused embedded
    library entries on save, which accounts for the smaller file.
2026-10-12 Fix BOM: R1 is an 0603 part, name T1 test pads
    R1 name and value said 0605/0805 while the board and the linked
    Digi-Key part (RMCF0603FT10K0) are 0603. T1 name changed from
    CAP_0603 to TEST1 since it is a test pad pair, not a capacitor.
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2026-10-12 BOM: constrain capacitor substitutions
    Capacitor rows now spell out what a substitute must be: X7R, 25V or
    higher, 0603, from Murata, TDK, Kyocera-AVX, KEMET or Taiyo Yuden.
    Leakage and long-term reliability matter more than value here, so a
    fab must not drop to a lower-tier parametric equivalent.
